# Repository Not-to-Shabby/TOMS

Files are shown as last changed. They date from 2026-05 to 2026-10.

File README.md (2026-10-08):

# Transportation Occupancy Monitoring System (TOMS)

> **TOMS v2 is in progress.** The system described below (Master/Slave terminals, Flutter app) is the first generation and now lives in [`archive/`](archive/README.md). v2 uses the conductor's phone as the card reader: see [`toms_android/`](toms_android/README.md), [`toms_backend/`](documentation/v2_progress.md) and [`toms_web/`](toms_web/), and the design notes in [`documentation/v2_decisions.md`](documentation/v2_decisions.md) and [`documentation/v2_progress.md`](documentation/v2_progress.md). The hardware drawings below are still current.

TOMS is a secure, offline-first, contactless transit ticketing and manifest system designed to modernize public utility vehicle operations (such as minibuses and modern jeepneys in Iligan City, Philippines). It replaces traditional manual ticket issuance and cash collection with a robust Master-Slave-Phone network architecture utilizing contactless NFC-DEP Peer-to-Peer communication, ESP-NOW wireless synchronization, and USB CDC-ACM mobile integration.

---

## 🚀 System Architecture (v1, archived)

TOMS is composed of three primary tiers:
1. **Slave Terminal (Tap / Interface Device)**
   * **Hardware:** Built on the ultra-compact **ESP32-S3 Super Mini** development board.
   * **Power Management:** Onboard TP4054 battery charging IC management with built-in resistor voltage divider (ratio 0.5) connected to GPIO 1 (ADC1_CH0) to monitor LiPo cell status.
   * **Peripherals:** PN532 NFC transceiver (configured in Target mode for NFC-DEP P2P at 424 kbps), ST7735S 128×160 TFT LCD (using LVGL 8.3 UI), and a tactile boarding trigger button.
   * **Functionality:** Passive interface that displays transaction UI, accepts button/tap inputs, generates QR receipts, and exchanges fast data frames with the Master.
2. **Master Handheld Terminal (Business Logic & Storage)**
   * **Hardware:** ESP32-S3 microcontroller.
   * **Functionality:** Conducts cryptographic operations, holds fare tables, acts as the transaction broker, writes records to an offline-first wear-leveled SPIFFS partition, and pipes live transactions to the operator's smartphone via USB CDC-ACM.
3. **Mobile Dashboard App (Cloud Gateway)**
   * **Framework:** Native Android App built with Flutter.
   * **Functionality:** Acts as the operator's primary screen, displays real-time boarding analytics, caches transactions in a local SQLite database, and pushes buffered records to a Supabase backend when an active internet connection is detected.

---

## 🛠️ Hardware Design Documentation

The physical prototypes were developed using Fritzing. Below are the designs (breadboard layouts, schematics, and PCB diagrams) for both the Master and Slave terminals.

### 1. Master Handheld Terminal

| View Type | Hardware Illustration |
|---|---|
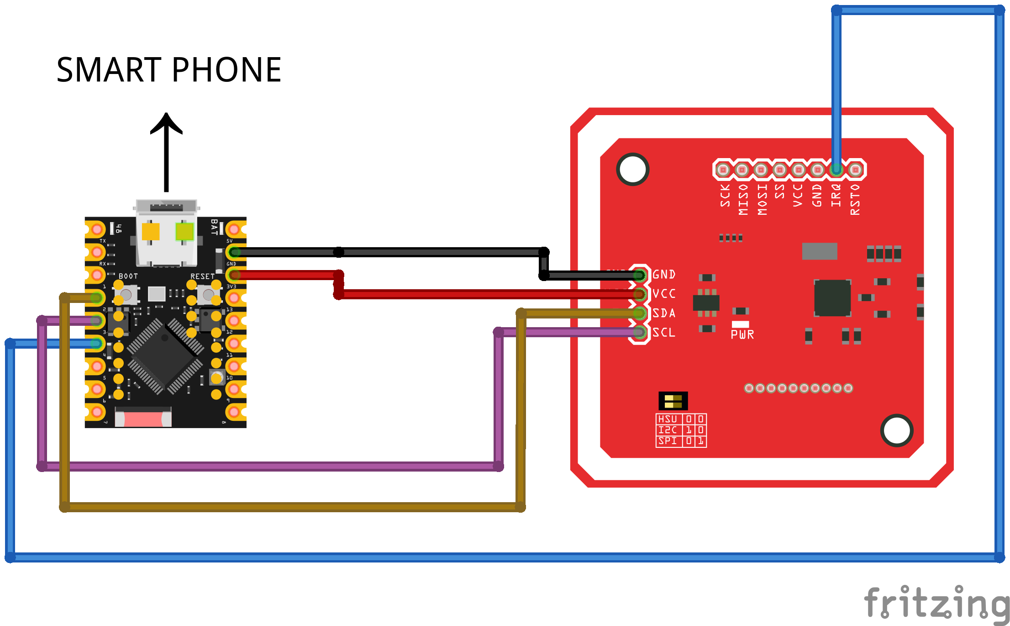
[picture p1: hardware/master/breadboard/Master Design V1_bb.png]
Master Breadboard
| **Breadboard Layout** |  |
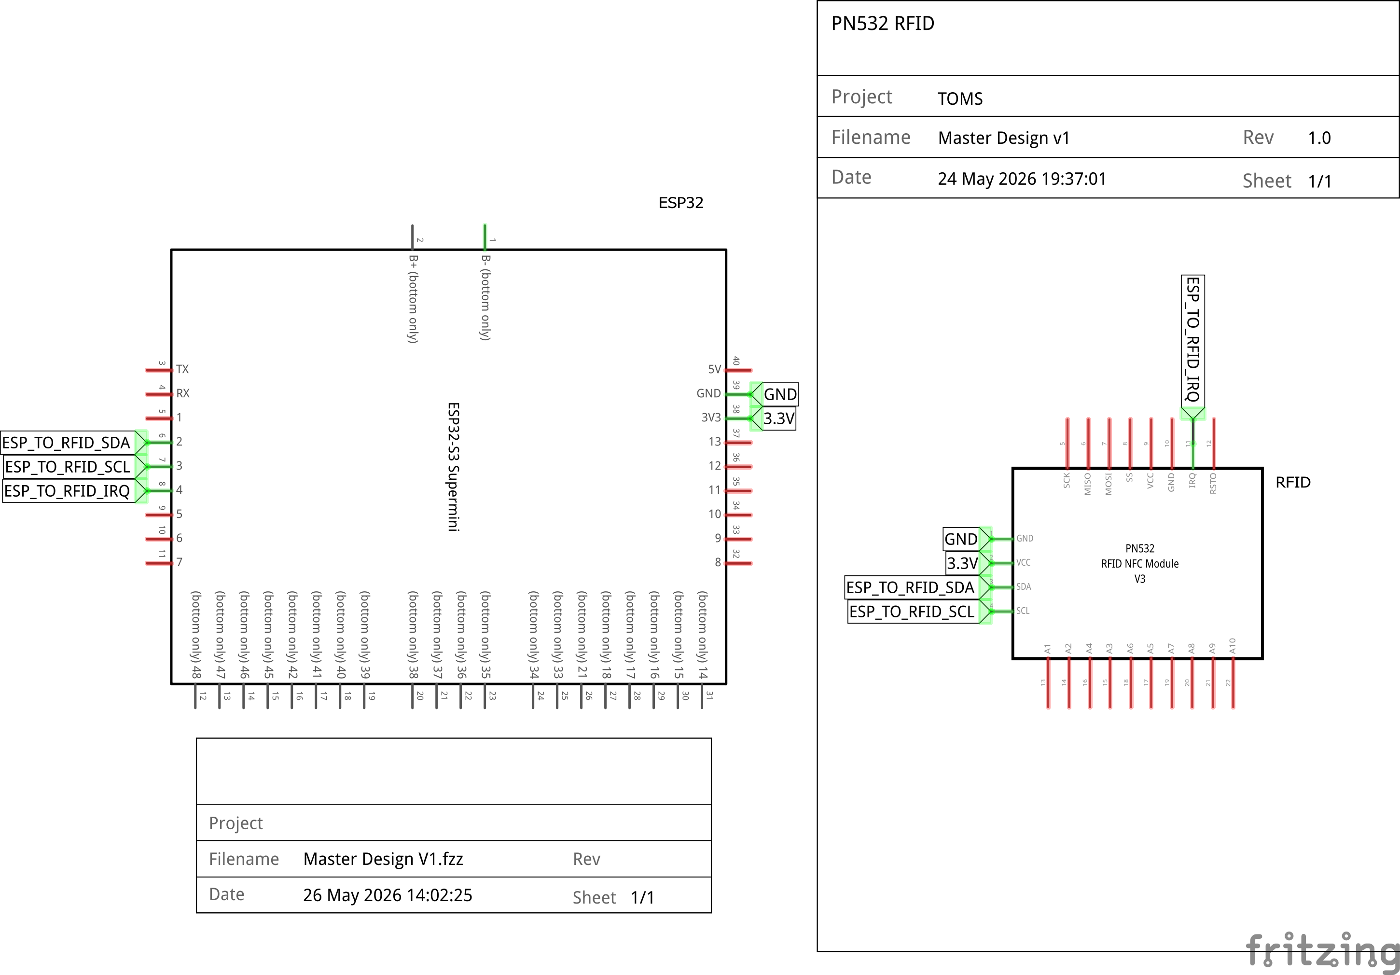
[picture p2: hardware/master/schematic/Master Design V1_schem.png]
Master Schematic
| **Schematic** |  |
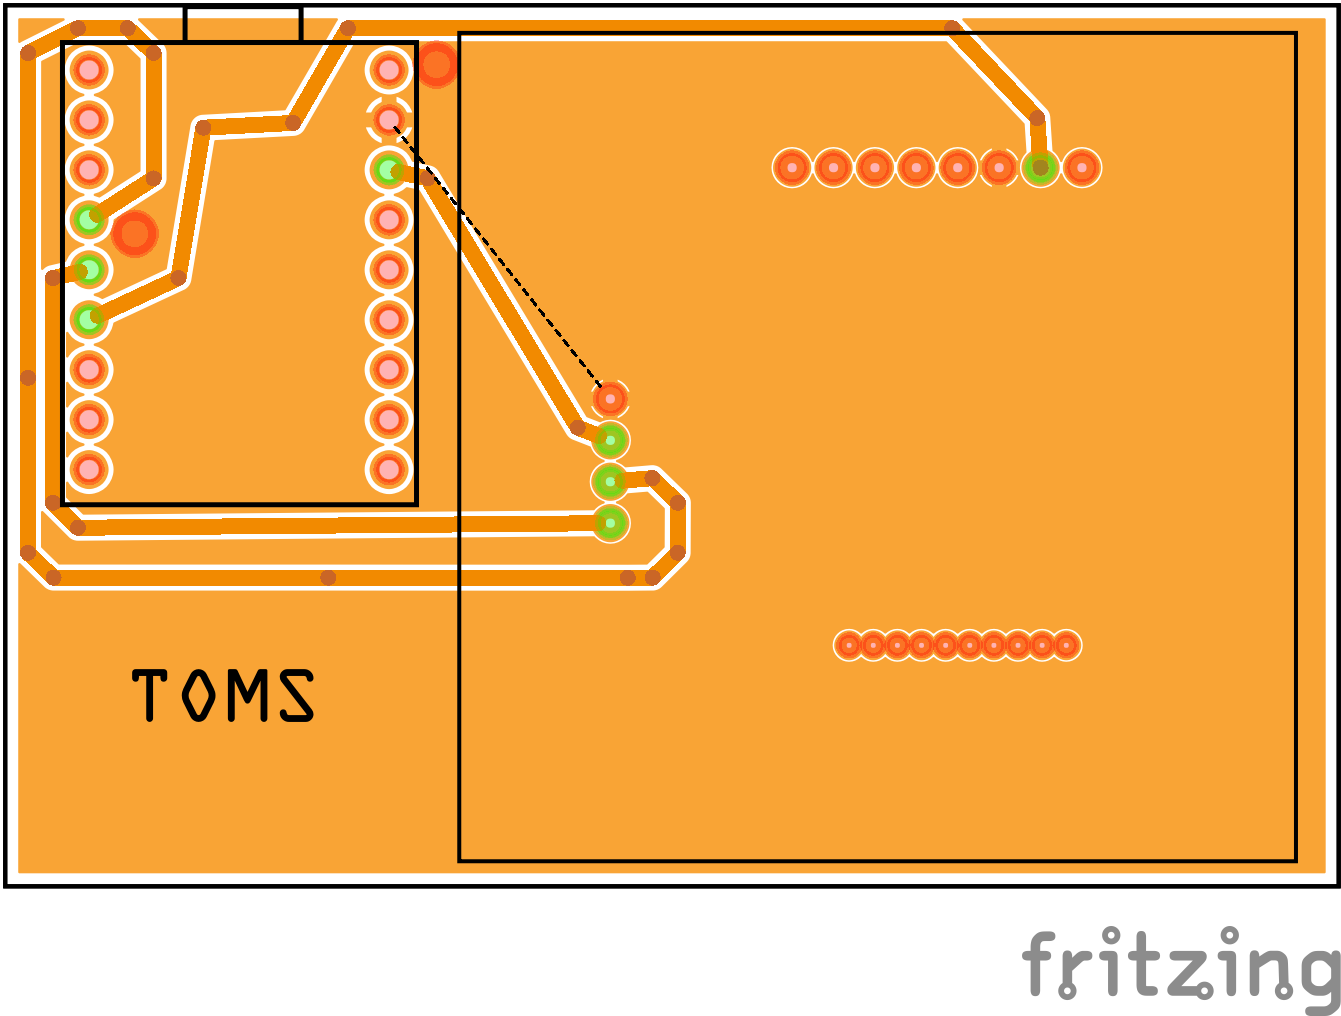
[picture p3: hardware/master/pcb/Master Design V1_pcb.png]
Master PCB
| **PCB Layout** |  |

### 2. Slave Terminal (ESP32-S3 Super Mini)

| View Type | Hardware Illustration |
|---|---|
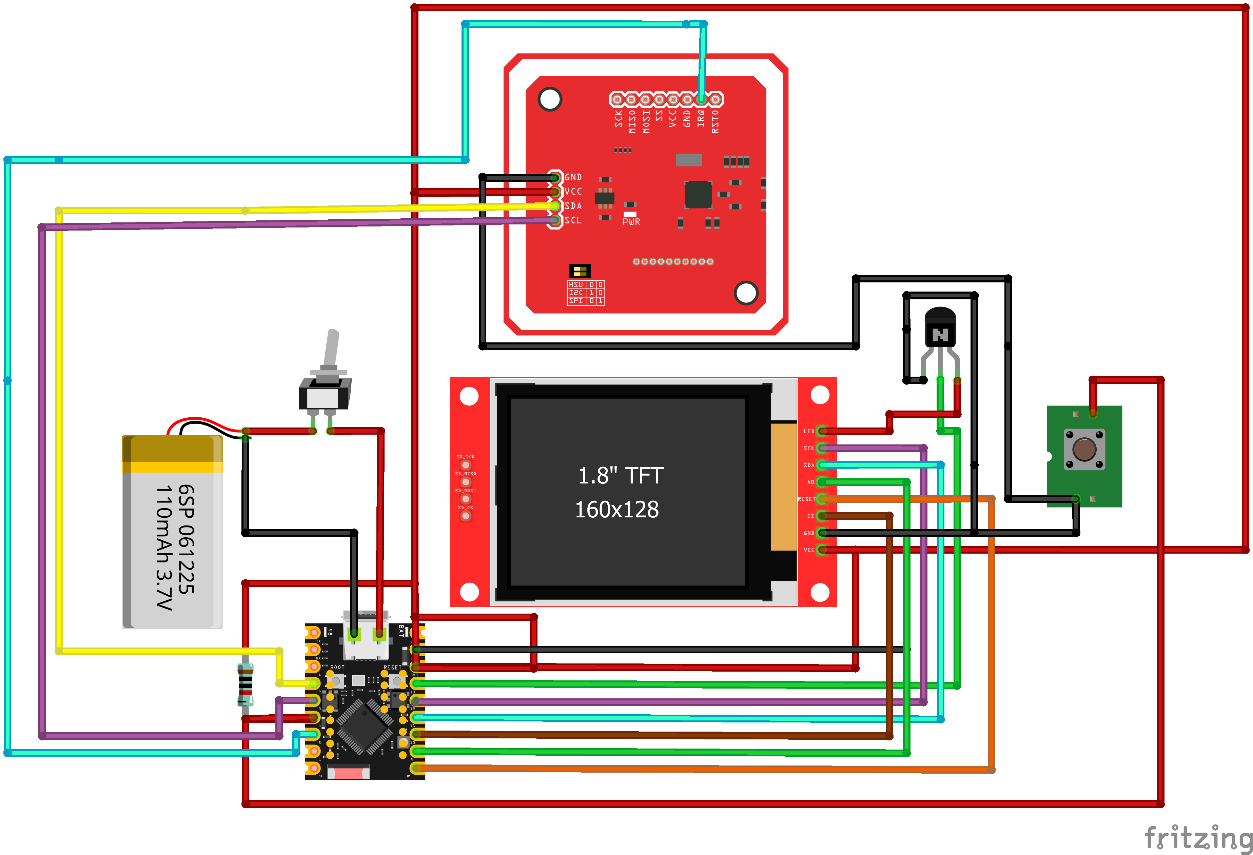
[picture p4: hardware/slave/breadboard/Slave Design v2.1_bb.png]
Slave Breadboard
| **Breadboard Layout** |  |
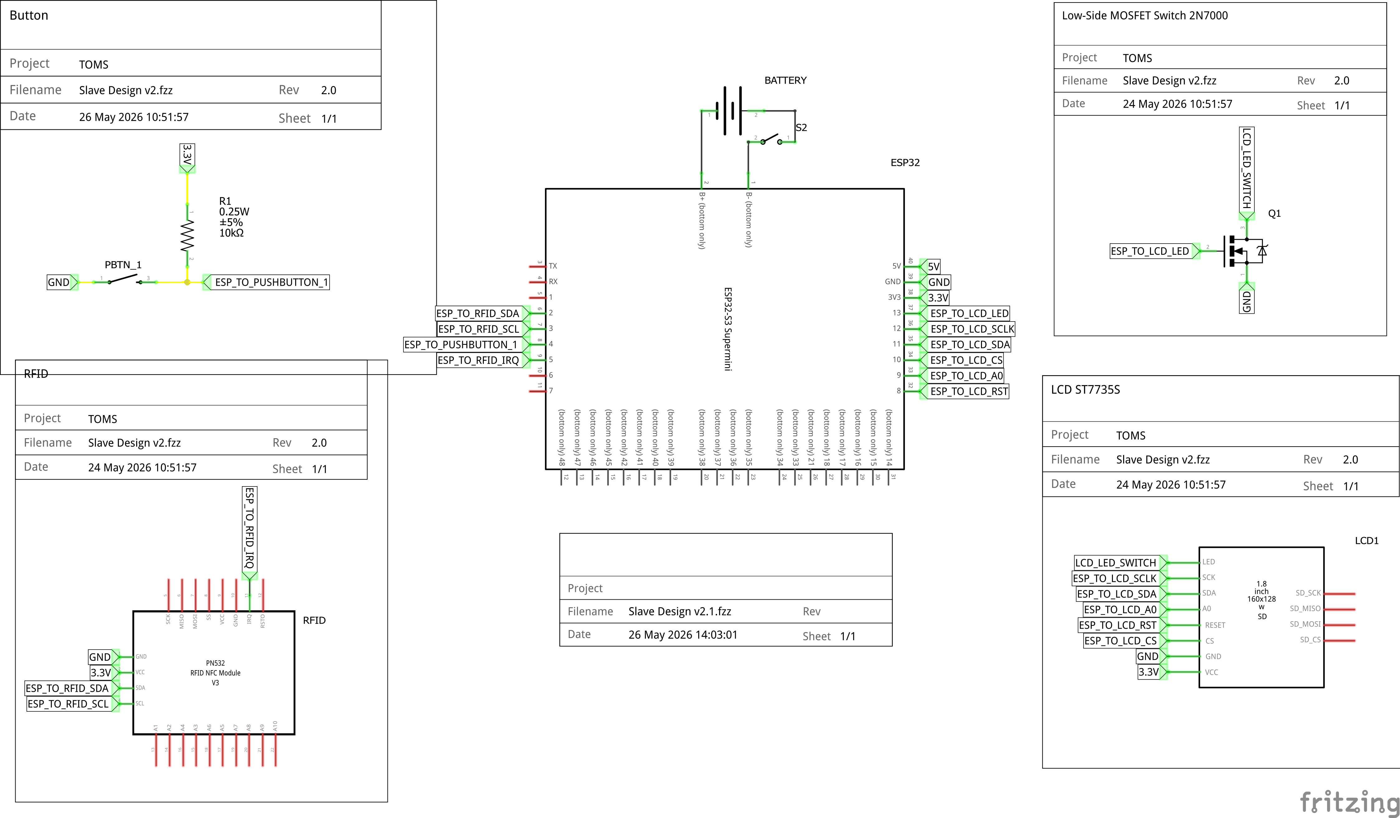
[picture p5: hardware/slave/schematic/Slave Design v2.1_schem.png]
Slave Schematic
| **Schematic** |  |
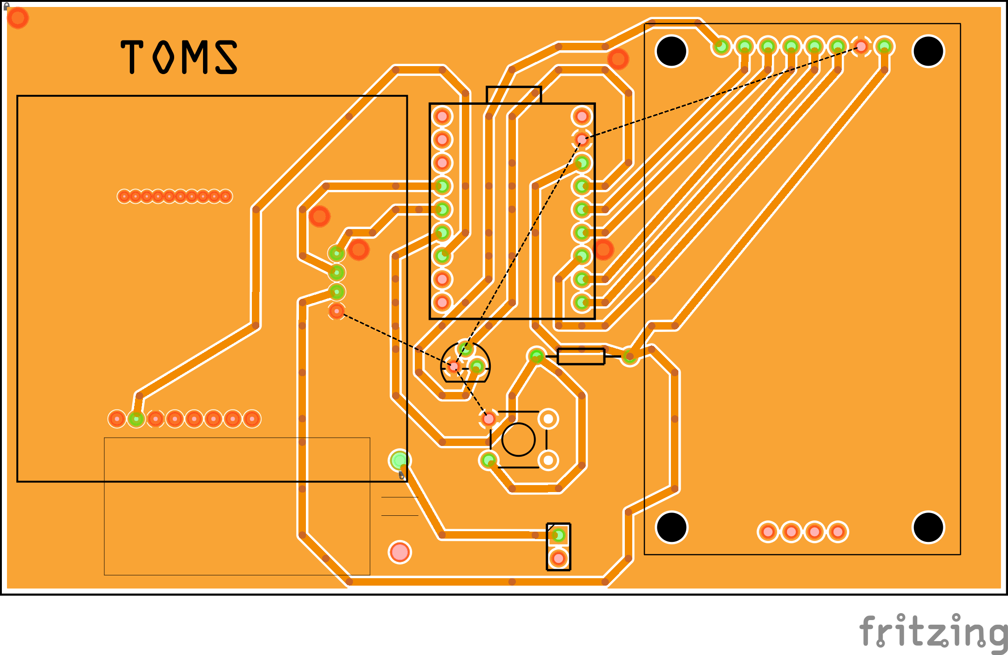
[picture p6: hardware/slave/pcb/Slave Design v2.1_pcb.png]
Slave PCB
| **PCB Layout** |  |

---

## 📡 Protocols & Security

* **Communication:** Standardized packet structure (`protocol.h`) with a 2-byte synchronization header (`0xAA55`), 1-byte length, 1-byte message type, 1-byte sequence number, variable payload, and a 2-byte CRC-16-CCITT checksum.
* **Optimistic NFC-DEP Transactions:** Master acts as the Initiator (`InJumpForDEP`) and Slave as the Target (`TgInitAsTarget`). A dictionary-based compression reduces boarding commands to 6 bytes to minimize RF communication window latency.
* **Authentication:** Device eFuse MAC validation combined with link-layer ESP-NOW CCMP (AES-128) security.

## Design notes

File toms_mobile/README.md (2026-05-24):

# toms_mobile

A new Flutter project.

## Getting Started

This project is a starting point for a Flutter application.

A few resources to get you started if this is your first Flutter project:

- [Lab: Write your first Flutter app](https://docs.flutter.dev/get-started/codelab)
- [Cookbook: Useful Flutter samples](https://docs.flutter.dev/cookbook)

For help getting started with Flutter development, view the
[online documentation](https://docs.flutter.dev/), which offers tutorials,
samples, guidance on mobile development, and a full API reference.

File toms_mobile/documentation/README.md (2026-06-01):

# TOMS Mobile Application Documentation

This document describes the application design, architecture, database configurations, APIs, user interface, program flow, and testing procedures for the TOMS (Transportation Occupancy Monitoring System) Flutter Mobile Application. It has been updated to reflect the completion of **Phase 4a**.

## System Architecture

The TOMS Mobile Application is a Flutter-based mobile app designed to run on the conductor's Android device. It acts as the orchestration bridge between the physical vehicle hardware (Master ESP32-S3), the passenger, and the cloud database:

1. Establishes a local physical link with the Master controller using an Android USB OTG connection, operating over a virtual serial CDC-ACM interface.
2. Serves as the real-time operator interface, showing vehicle occupancy, active routes, current passenger records, and GPS-aware proximity alarms.
3. Provides an offline-first transaction database, caching passenger boarding logs locally when mobile signals are unavailable.
4. Orchestrates synchronisation queues to push cached passenger records to the company REST API, using secure JWT-based authentication.

```mermaid
graph TD
    subgraph Conductor Mobile
        UI[Flutter Home Shell]
        AppState[AppState Provider]
        Sqlite[(SQLite Local Cache)]
        UsbService[UsbService CDC-ACM]
        SyncService[SyncService]
        AuthService[AuthService]
        GpsService[Gps & Proximity]
    end
    
    subgraph Vehicle Hardware
        Master[ESP32-S3 Master]
        Slave[Slave Terminals]
    end
    
    subgraph Cloud
        Backend[(Company Server / Cloud Database)]
    end
    
    UsbService -- USB OTG / JSON-Line -- Master
    Master -- ESP-NOW / P2P -- Slave
    UsbService --> AppState
    AppState --> UI
    AppState --> Sqlite
    GpsService --> AppState
    AuthService --> SyncService
    AppState --> SyncService
    SyncService -- HTTPS REST (JWT Auth) -- Backend
```

## Application Architecture

The mobile application utilizes a clean Model-View-Service architecture built around the Provider state-management framework to achieve separation of concerns:

* **View Layer (Material 3)**:
  * `HomeShell`: A Swipeable PageView bridging the primary workflows.
  * `BoardingScreen`: Full-screen UI for generating passenger tickets and managing the pending queue.
  * `DashboardScreen`: Real-time Occupancy Panel, active passenger slots, and diagnostic console.
  * `ShiftHistoryScreen`: Grouped daily transaction logs with JSON export capabilities.
* **Service Layer**: Decoupled singletons managing background hardware and data tasks:
  * `UsbService`: Manages USB serial lifecycles, parses incoming JSON frames.
  * `AuthService`: Manages JWT tokens in secure storage and vehicle assignment states.
  * `DatabaseService`: Manages SQLite operations, schema upgrades, and local query execution.
  * `SessionService`: Manages boarding queues, active passenger sessions, base fare calculations, and discount models.
  * `OccupancyService`: Computes dynamic slot allocations and publishes real-time occupancy rates based on vehicle capacity.
  * `GpsService & ProximityService`: Tracks the bus's physical location against mapped `TransitStops` and triggers local alarms when nearing a passenger's destination.
  * `ConnectivityService`: Monitors network status changes using the connectivity plugin.
  * `SyncService`: Stores events locally and flushes the synchronization queue automatically upon reconnection, providing progress callbacks to the UI.
* **State Orchestrator (`AppState`)**: Directs the flow between hardware events, UI state, and database transactions.

## Offline-First & Shift Lifecycles

The app implements a strict offline-first design:
* **Auth & Assignment**: The app is gated behind `LoginScreen` and `VehicleAssignmentScreen`. A shift does not begin until the conductor selects a vehicle, locking in the `maxCapacity`.
* **Local Caching**: Incoming USB passenger events (NFC taps, button presses) are evaluated against the pending queue, serialised into local SQLite tables, and immediately confirmed locally.
* **Store-and-Forward Sync**: The `SyncService` operates asynchronously. It batches unsynced records from the SQLite database. If the device is offline, it waits. Upon reconnection, it flushes the queue to the backend. A `_SyncStatusBar` provides UI feedback.
* **End of Shift**: Conductors invoke `AppState.endShift()` to clear active sessions and log out of the vehicle. If the backend is unavailable, the conductor can manually extract their shift logs as a JSON file via Bluetooth or Email using `share_plus`.

## Hardware Pin Assignment & Connectivity

Because the mobile application is a software layer running on commercial Android hardware, it does not directly manage low-level GPIO pin configurations. Instead, it accesses hardware interfaces through:
* **Interface**: USB Controller on the Android SoC.
* **Protocol Mode**: Configured in USB Host Mode via the Android SDK (`android.hardware.usb.host` feature).
* **Physical Connection**: Android USB Type-C interface connected to the Master ESP32-S3 via a USB OTG cable.

## Required Libraries

The following dependencies are declared inside `pubspec.yaml`:

1. `usb_serial`: Wraps Android USB host APIs to discover, open, and communicate with USB-to-serial chips without device root.
2. `provider`: State-management container used to inject services.
3. `sqflite`: SQLite database plugin for local caching.
4. `flutter_secure_storage`: Encrypts the company JWT token and securely stores the conductor's credentials.
5. `geolocator`: Accesses phone GPS for coordinate tracking.
6. `vibration` & `flutter_local_notifications`: Sounds haptic and visual alarms for unpaid passengers approaching their stops.
7. `share_plus`: Exports shift JSON summaries for offline terminal reconciliation.
8. `connectivity_plus`: Listens to network connectivity events to trigger automatic API syncing.
9. `lucide_icons` & `google_fonts`: Tailwind UI / modern typography.

## Protocol Used in Hardware Abstraction Layer

The application-level HAL protocol uses newline-delimited JSON objects transmitted over the USB virtual serial port at 115200 baud:

* **Conductor Phone to Master Commands**:
  * Handshake: `{"cmd":"handshake"}`
  * Get Status: `{"cmd":"get_status"}`
  * Board Passenger: `{"cmd":"board", "uid":"...", "fare":1300, "seat":1, "route":1, "vehicle_id":"..."}`
* **Master to Conductor Phone Events**:
  * Acknowledgment: `{"evt":"ack", ...}`
  * Status Diagnostics: `{"evt":"status", ...}`
  * NFC Card Tap: `{"evt":"nfc_tap", "uid":"A1B2C3D4E5F6", "seat":0}`
  * Button Boarding Request: `{"evt":"button_press", "mac":"A1:B2:C3:D4:E5:F6"}`
  * Passenger Alighted: `{"evt":"release", "mac":"A1:B2:C3:D4:E5:F6"}`
  * Error Warning: `{"evt":"error", "msg":...}`

## Program Flow Table

| Step | State/Action | Condition / Input | Output / State Transition |
|---|---|---|---|
| 1 | Boot Initialization | App launch | Instantiates SQLite services, registers providers, validates JWT token. Routes to `LoginScreen` or `VehicleAssignmentScreen`. |
| 2 | Shift Start | Vehicle Selected | Sets `maxCapacity`, routes to `HomeShell`, triggers automatic USB scanning loop. |
| 3 | Boarding Prep | Conductor interacts | Conductor selects destination/type. GPS auto-suggests nearest boarding stop. Passenger added to `SessionService.pendingQueue`. |
| 4 | USB Device Connected | Master USB plugged in | Opens serial port, 115200 baud, transmits `handshake`. Updates Dashboard status. |
| 5 | Passenger Boarding Request | NFC Tap OR Button Press | Fires `nfc_tap` / `button_press` over USB. App checks if a queued ticket exists, assigns the ticket, sends `board` command, and pushes a `board` event to `SyncService`. |
| 6 | Payment Trigger | Conductor collects fare | Conductor collects cash. Marks slot as PAID. Clears proximity alarms. Pushes a `payment` event to sync queue. |
| 7 | Proximity Alarm | GPS approaches destination | `ProximityService` calculates distance < 200m. If unpaid, triggers `Vibration` and `ProximityAlarmBanner`. |
| 8 | Passenger Alighting | Slave Long Press (3s) | Slave sends release notification. Phone receives `release` event, frees the slot, and syncs release. |
| 9 | Cloud Sync Queue | Event added to sync queue | If connectivity is detected, POSTs to backend using JWT Auth. Updates UI sync badge on success. |

## Security Architecture

1. **Network Security**: Connects to cloud endpoints over HTTPS (TLS encryption) to prevent MITM attacks.
2. **API Authentication**: The `SyncService` dynamically requests a bearer token from `AuthService` (`Authorization: Bearer <token>`). Tokens are securely encrypted on disk.
3. **Data Protection**: Local transactions are segregated by shift. Debug logs are routed through Flutter's `debugPrint`, preventing leakage to Android logcat in release builds.

## Planned Features (Upcoming Phases)

1. **Route Builder Syncing**: Dynamic injection of `TransitStop` coordinates from the backend API replacing the static `stops.json`.
2. **Master USB Configuration Push**: Pushing updated fare dictionaries and vehicle capacities dynamically to the Master's NVS memory upon shift start.

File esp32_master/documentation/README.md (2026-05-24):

# TOMS Master Firmware Documentation

This document describes the firmware design, system architecture, pin assignments, software framework, APIs, program flow, and testing procedures for the TOMS (Transit Monitoring System) Master device.

## System Architecture

The Transit Monitoring System (TOMS) is designed to coordinate vehicle passenger check-ins, manage fare calculations, and store transactional records for public transit operations. The Master device is the central controller inside the vehicle:

1. Connects to the conductor's Android mobile device (running the Flutter app) via a USB CDC-ACM virtual serial interface (USB OTG).
2. Manages synchronization with Slave devices via two interfaces: **NFC-DEP peer-to-peer** (PN532 module, physical tap) or wirelessly (ESP-NOW).
3. Buffers and logs all check-in events in a local SPIFFS flash partition to prevent data loss in signal dead zones (offline-first architecture).
4. Monitors battery voltage using an integrated ADC channel to report power status.
5. Uses a **dictionary-based compact NFC exchange** — both Master and Slave share a pre-synced fare dictionary. NFC payloads carry only indices (6 bytes), not raw data (40 bytes).

```mermaid
graph TD
    subgraph Vehicle Cabin
        Master[ESP32-S3 Master Controller]
        Slave[ESP32-S3 Slave Unit]
    end
    
    subgraph Conductor UI
        Mobile[Android Flutter App]
    end
    
    subgraph Cloud Backend
        Supabase[(Supabase Database)]
    end
    
    Master -- USB OTG / CDC-ACM JSON-Line -- Mobile
    Master -- ESP-NOW 2.4 GHz AES-256 -- Slave
    Master -- PN532 NFC-DEP P2P I2C -- Slave
    Mobile -- HTTPS / Offline Sync -- Supabase
```

## Firmware Architecture

The Master firmware is built on top of the ESP-IDF RTOS environment, distributing tasks across the dual cores of the ESP32-S3 microcontroller to ensure real-time responsiveness.

* Core 0: Manages the USB CDC serial communication thread, the NFC P2P sync task (PN532 Initiator), SPIFFS storage operations, and battery monitoring.
* Core 1: Dedicated to the latency-critical ESP-NOW wireless network stack, processing wireless packets and driving immediate acknowledgments.

```mermaid
graph TD
    subgraph Core 0
        usb_cdc_task[USB CDC Task]
        nfc_sync_task[NFC Sync Task - PN532 Initiator]
        storage_flush_task[Storage Flush Task]
        power_adc[Battery Monitoring]
    end
    subgraph Core 1
        espnow_handler_task[ESP-NOW Handler Task]
    end
    
    app_main[app_main Entry] --> usb_cdc_task
    app_main --> nfc_sync_task
    app_main --> espnow_handler_task
    app_main --> storage_flush_task
```

## Firmware Design

The firmware relies on an event-driven design pattern utilizing FreeRTOS queues and callbacks. Each peripheral driver (USB, NFC, ESP-NOW) is decoupled from the main coordination logic:
* Incoming USB packets from the conductor's phone trigger a receive callback which executes parsing routines.
* The NFC PN532 Initiator task polls for NFC-DEP targets every 250ms. On tap, the Slave's NFCID3 (containing its eFuse MAC) identifies it without a separate handshake.
* A **two-phase optimistic transaction** model is used: Phase 1 (NFC tap) increments the passenger counter immediately, Phase 2 (ESP-NOW PASSENGER_BOARD) confirms the transaction asynchronously.
* Wireless ESP-NOW messages are loaded into a thread-safe FreeRTOS queue and processed sequentially by a dedicated high-priority task.
* Transactions are cached in binary format inside SPIFFS files and written in blocks to extend flash endurance.
* A **fare dictionary** stored in NVS enables compact NFC payloads — only a fare_id index (1 byte) is transmitted instead of full fare/route data.

## Hardware Pin Assignment

The Master device is built on the ESP32-S3 Super Mini platform. The hardware pins are configured as follows:

| Interface | Pin Name | GPIO Pin | Pin Type | Description |
|---|---|---|---|---|
| NFC I2C | TOMS_NFC_I2C_SDA | GPIO 2 | Bidirectional | I2C data line to PN532 module |
| NFC I2C | TOMS_NFC_I2C_SCL | GPIO 3 | Output | I2C clock line to PN532 module |
| NFC IRQ | TOMS_NFC_IRQ_PIN | GPIO 4 | Input | PN532 interrupt (active LOW, tag ready) |
| Power | TOMS_BATTERY_ADC_CHANNEL | GPIO 1 (ADC1_CH0) | Analog Input | Measures battery voltage via a 0.5 voltage divider |
| USB OTG | Native USB D- | GPIO 19 | Bidirectional | Native USB signal for CDC-ACM virtual serial port |
| USB OTG | Native USB D+ | GPIO 20 | Bidirectional | Native USB signal for CDC-ACM virtual serial port |

## Software Framework Used

The firmware is developed using PlatformIO with the Espressif ESP-IDF software development framework (v5.0.0 or higher). This framework provides the underlying FreeRTOS kernel, virtual file system (VFS) interface, hardware abstraction drivers, and wireless protocol stacks.

## Required Libraries

The following dependencies are declared and loaded via the IDF Component Manager:

1. espressif/esp_tinyusb (version ^1): Configures the ESP32-S3's internal USB OTG controller into CDC-ACM device class mode.
2. mbedtls: Part of the ESP-IDF core library, providing hardware-accelerated cryptographic operations.
3. esp_wifi and esp_now: Core ESP-IDF libraries managing the RF driver, Wi-Fi Station layer, and raw connectionless frame transfers.
4. esp_spiffs and nvs_flash: Core ESP-IDF subsystems for file storage and key-value storage.
5. PN532 I2C driver: Custom shared library (`shared_lib/pn532/`) implementing the NXP PN532 NFC controller protocol over I2C.

## Protocol Used in Hardware Abstraction Layer

The system uses a custom application-level framing protocol (defined in `protocol.h`) to encapsulate messages sent over both NFC-DEP and wireless ESP-NOW:

* framing: `[Sync Word (0xAA55)][Length (1 byte)][Type (1 byte)][Sequence (1 byte)][Payload (0-240 bytes)][CRC-16-CCITT (2 bytes)]`
* NFC compact format: `[MSG_TYPE (1 byte)][fare_id (1 byte)][seat (1 byte)][timestamp (4 bytes)]` — 7 bytes total for boarding commands
* encryption: Wireless payloads (ESP-NOW) are encrypted with application-level AES-256-CBC using a key loaded from NVS, running on top of ESP-NOW's native AES-128 CCMP link encryption.
* fare dictionary: Both devices share a pre-synced lookup table in NVS indexed by `fare_id`. Only the index is transmitted over NFC.

## Program Flow Table

| Step | State/Action | Condition / Input | Output / State Transition |
|---|---|---|---|
| 1 | Boot Initialization | Power on / Reset | Initializes NVS, mounts SPIFFS, loads AES key, initializes Wi-Fi/ESP-NOW, configures USB CDC, initializes PN532 NFC, loads fare dictionary, reads ADC, launches FreeRTOS tasks. Transition to Idle Listening. |
| 2 | Idle Listening | Waiting for interrupts / messages | NFC task polls InJumpForDEP every 250ms, USB CDC stream is monitored, ESP-NOW event queue is processed. |
| 3 | USB Message Received | JSON command over USB CDC | Decodes JSON command. If `handshake`, replies with device info (MAC, battery, pending logs). If `get_status`, returns full diagnostics. If `sync_fare_table`, processes config. |
| 4 | NFC Tap Detection | PN532 InJumpForDEP succeeds | DEP link established. Slave NFCID3 = eFuse MAC extracted. Phase 1: Optimistic count — passenger counter incremented, phone notified with `nfc_tap` event. |
| 5 | NFC Board Command | DEP link active | Sends compact NFC_BOARD_CMD (fare_id + seat + timestamp, 6 bytes) via InDataExchange. Slave responds with NFC_ACK. Link released. Cooldown (1.5s anti-double-tap). |
| 6 | ESP-NOW Confirmation | Receives TOMS_MSG_PASSENGER_BOARD wirelessly | Phase 2: Transaction confirmed. Logs passenger event to SPIFFS. Forwards confirmed transaction to phone via USB. |
| 7 | ESP-NOW Button Event | Receives TOMS_MSG_BUTTON_PRESS wirelessly | Transmits `button_press` event to Mobile via USB. Sends wireless ACK. Dispatches TOMS_MSG_BOARD_COMMAND back to the sender Slave MAC. |
| 8 | Periodic Storage Flush | 60 seconds timer elapsed | Storage task runs, clears old synced transaction files (`.done`), and logs active memory usage stats. |

## Program Flowchart

```mermaid
flowchart TD
    Init[Boot & Subsystem Init] --> Idle[Idle Listening Loop]
    
    Idle -->|USB JSON Rx| USB_Cmd{Decode Command}
    USB_Cmd -->|handshake| USB_Handshake[Send device status JSON] --> Idle
    USB_Cmd -->|get_status| USB_Status[Send diagnostic status JSON] --> Idle
    USB_Cmd -->|sync_fare_table| USB_Fare[Process/Sync Fare Configuration] --> Idle
    
    Idle -->|PN532 InJumpForDEP| NFC_Detect{NFC Target Found?}
    NFC_Detect -->|No| Idle
    NFC_Detect -->|Yes| NFC_Tap[Phase 1: Optimistic Count - Notify Phone]
    NFC_Tap --> NFC_Send[Send NFC_BOARD_CMD 6 bytes]
    NFC_Send --> NFC_ACK{Slave ACK?}
    NFC_ACK -->|Yes| NFC_Cooldown[1.5s Anti-Double-Tap Cooldown] --> Idle
    NFC_ACK -->|No/Error| NFC_Reset[Reset PN532] --> Idle
    
    Idle -->|ESP-NOW Rx| EN_Msg{Decode Msg Type}
    EN_Msg -->|PASSENGER_BOARD| EN_Confirm[Phase 2: Confirm Transaction - Log & Forward] --> Idle
    EN_Msg -->|BUTTON_PRESS| EN_Button[Forward to Phone & Send BOARD_COMMAND via ESP-NOW] --> Idle
    EN_Msg -->|HEARTBEAT| EN_Hb[Log Slave presence] --> Idle
    
    Idle -->|60s Timer| Storage_Task[Erase synced .done files & log stats] --> Idle
```

## APIs in the Codebase

### Implemented APIs

* `int toms_storage_init(void)`: Mounts VFS SPIFFS and initializes the NVS flash interface.
* `bool toms_storage_log_event(const toms_passenger_event_t *event)`: Appends a transaction binary packet to the active SPIFFS file.
* `int toms_storage_get_pending_count(void)`: Returns the number of unsynced transaction files currently cached.
* `bool toms_storage_read_pending(uint8_t *buf, size_t buf_size, size_t *out_len, char *fname)`: Reads an unsynced transaction file.
* `bool toms_storage_mark_synced(const char *fname)`: Renames a file by changing its extension to `.done`.
* `void toms_storage_cleanup(void)`: Iterates over the storage partition and deletes all files marked `.done`.
* `int toms_crypto_init(void)`: Loads the AES-256 key from NVS.
* `bool toms_crypto_encrypt(...)`: Encrypts a payload buffer with AES-256-CBC.
* `bool toms_crypto_decrypt(...)`: Decrypts an IV-prefixed AES-256-CBC ciphertext buffer.
* `int toms_espnow_init(const uint8_t *pmk)`: Initializes Wi-Fi in Station mode and sets up ESP-NOW.
* `bool toms_espnow_send(const uint8_t *dst_mac, const toms_packet_t *pkt)`: Encrypts, serializes, and transmits a wireless packet.
* `int toms_usb_cdc_init(void)`: Configures the USB controller and CDC descriptors.
* `int toms_usb_cdc_send(const char *json)`: Pushes a JSON string to the mobile app.
* `int toms_nfc_sync_init(void)`: Initializes PN532 over I2C as NFC-DEP Initiator.
* `void toms_nfc_sync_set_tap_cb(toms_nfc_tap_cb_t cb)`: Registers callback for NFC tap detection.
* `void toms_nfc_sync_set_fare(uint8_t fare_id, uint8_t seat)`: Sets active fare for next NFC tap.
* `void toms_nfc_sync_task(void *arg)`: NFC Initiator polling task (FreeRTOS).
* `toms_nfc_state_t toms_nfc_sync_get_state(void)`: Returns current NFC state.
* `esp_err_t toms_fare_dict_load(toms_fare_dict_t *dict)`: Loads fare dictionary from NVS.
* `const toms_fare_entry_t *toms_fare_dict_lookup(const toms_fare_dict_t *dict, uint8_t fare_id)`: Looks up a fare entry by ID.
* `int toms_power_init(void)`: Configures the ADC1 peripheral for battery readings.
* `uint32_t toms_power_get_battery_mv(void)`: Returns raw battery voltage in millivolts.
* `uint8_t toms_power_get_battery_pct(void)`: Returns battery state of charge percentage.

### Planned to be Implemented

* `bool toms_storage_set_fare_table(const uint8_t *data, size_t len)`: Planned API to persist updated route pricing tables received from the mobile app to NVS.
* `bool toms_storage_get_fare_table(uint8_t *buf, size_t max_len, size_t *out_len)`: Planned API to read pricing tables from NVS for syncing to Slaves.
* `void toms_power_enter_light_sleep(void)`: Planned power-saving API.

## Planned / Implemented User Acceptance Testing (UAT)

1. USB OTG Communication: Conductor connects their Android phone running the Flutter app. The Master must establish a virtual serial link, complete the handshake within 1.5 seconds, and report its battery percentage and file counters.
2. NFC Tap Boarding: Conductor taps a Slave device against the Master's PN532 antenna. The Master must detect the NFC-DEP link, read the Slave's UID from NFCID3, send a compact BOARD_CMD (6 bytes), receive ACK, and notify the phone with an optimistic `nfc_tap` event — all within 300ms.
3. ESP-NOW Confirmation: After the Slave processes the boarding (shows fare, renders QR), it sends PASSENGER_BOARD via ESP-NOW. The Master must confirm the transaction and forward it to the phone.
4. Offline Logging Validation: Disconnect the mobile device. Trigger 10 boarding events. The Master must successfully write all 10 records to SPIFFS. Reconnect the mobile device; the Master must sync the 10 stored records.
5. AES-256 Payload Security: Capture ESP-NOW traffic using an external sniffer. Payload content must be fully encrypted.

## Testing and Validation (Hardware Focus: Module & Power Testing)

### Power Measurement and Calibrations
* Battery Monitor Voltage Divider: The hardware employs a 100k ohm / 100k ohm (0.5 ratio) resistor divider to bring battery voltage (3.0V - 4.2V) within the ESP32-S3's ADC input range.
* ADC Calibration: The codebase utilizes `esp_adc_cal_characterize` to configure raw ADC counts against factory-fused eFuse calibration values.
* Threshold Validation: The firmware implements a low battery warn threshold at 3300mV (~20% capacity) and a critical shutdown threshold at 3100mV.

### Module Interface Verification
* PN532 I2C Communication: The I2C bus operates at 400 kHz. IRQ pin (GPIO 4) is used for zero-latency response detection. The PN532 firmware version is verified on every boot.
* NFC-DEP Link Timing: At 424 kbps, the NFC data exchange (6-byte command + 1-byte ACK) takes under 1ms on the RF layer. Total tap time is ~100-150ms, dominated by DEP link setup.
* RF Verification: Wi-Fi output power is adjusted to ensure reliable ESP-NOW operation within a 15-meter vehicle cabin radius.

## Potential TODOs in the Codebase

1. Parsing of JSON Fare Tables: Integrate `cjson` parser inside `usb_cdc.c` / `app_main.c` to parse fare arrays received over USB and update the fare dictionary.
2. NVS Storage for Fare Tables: Implement `toms_fare_dict_save()` to persist fare dictionaries received from the phone and sync to Slaves.
3. Secure Key Provisioning: Establish a protocol command to provision the AES-256 key via USB CDC on assembly.

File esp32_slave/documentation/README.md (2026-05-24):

# TOMS Slave Firmware Documentation

This document describes the firmware design, system architecture, pin assignments, software framework, APIs, program flow, and testing procedures for the TOMS (Transit Monitoring System) Passenger Slave device.

## System Architecture

The Passenger Slave device acts as the interface for passengers in the vehicle cabin. Its main responsibilities are:

1. Displaying welcoming prompts, fare details, seat numbers, and transaction status screens.
2. Generating and rendering high-contrast QR codes on the screen that act as passenger check-in receipts.
3. Receiving manual check-in requests via a physical wake-up button.
4. Communicating with the Master device via **NFC-DEP peer-to-peer** (PN532 module, physical tap) or wirelessly (ESP-NOW).
5. Minimizing battery power consumption using aggressive deep sleep modes, waking up only upon button presses or timer-based heartbeats.
6. Using a **fare dictionary** to expand compact NFC commands into full boarding data locally.

```mermaid
graph TD
    subgraph Vehicle Cabin
        Master[ESP32-S3 Master Controller]
        Slave[ESP32-S3 Slave Unit]
    end
    
    subgraph Slave Subsystems
        Button[Wake Button / Interrupt]
        TFT[ST7735S TFT Screen]
        LVGL[LVGL UI Engine]
        PN532_S[PN532 NFC Module - Target]
    end
    
    Master -- ESP-NOW Wireless / NFC-DEP P2P -- Slave
    Slave --> Button
    Slave --> TFT
    Slave --> LVGL
    Slave --> PN532_S
```

## Firmware Architecture

The Slave firmware is structured around a passive, master-driven architecture designed to minimize active runtime and maximize battery life. It divides operations into dedicated FreeRTOS tasks pinned to the ESP32-S3's dual cores:

* Core 0: Executes low-priority and user-interface tasks: LVGL timer ticks, physical button debouncing, NFC Target listener, and the main coordination state machine.
* Core 1: Runs the latency-sensitive wireless ESP-NOW handler task to process incoming commands and send ACKs.

```mermaid
graph TD
    subgraph Core 0
        lvgl_timer_task[LVGL UI Task]
        button_task[Button Interrupt/Debounce Task]
        nfc_sync_task[NFC Target Listener Task]
        main_logic_task[Main Orchestrator Task]
    end
    subgraph Core 1
        espnow_handler_task[ESP-NOW Task]
    end
    
    app_main[app_main Entry] --> lvgl_timer_task
    app_main --> button_task
    app_main --> nfc_sync_task
    app_main --> main_logic_task
    app_main --> espnow_handler_task
```

## Firmware Design

The firmware is designed around a passive state-machine:
* Sleep Mode: Microcontroller sits in deep sleep (current consumption under 15 microamps). It wakes via an ext0 RTC interrupt on the button or a timer.
* Timer Wake: Wakes every 5 minutes, transmits an ESP-NOW heartbeat containing its battery/status, and immediately sleeps.
* Active Mode: Wakes on button press. Initializes peripherals (including PN532 NFC as Target), starts a 30-second idle timer, and shows the Welcome screen.
* NFC Tap Handling: The PN532 waits in Target mode (TgInitAsTarget, DEP-only, IRQ-driven). When the Master taps, it receives a compact NFC_BOARD_CMD (fare_id + seat + timestamp), looks up the fare_id in its local dictionary, and triggers the boarding flow.
* Transaction Handling: Displays processing screen, fare details, and renders the QR receipt. Sends a `PASSENGER_BOARD` confirmation via ESP-NOW, and returns to Welcome.

## Hardware Pin Assignment

The Slave is implemented on the ESP32-S3 Super Mini platform. The hardware pins are configured as follows:

| Interface | Pin Name | GPIO Pin | Pin Type | Description |
|---|---|---|---|---|
| NFC I2C | TOMS_NFC_I2C_SDA | GPIO 2 | Bidirectional | I2C data line to PN532 module |
| NFC I2C | TOMS_NFC_I2C_SCL | GPIO 3 | Output | I2C clock line to PN532 module |
| NFC IRQ | TOMS_NFC_IRQ_PIN | GPIO 5 | Input | PN532 interrupt (active LOW) |
| SPI Display | TOMS_LCD_PIN_SDA | GPIO 11 | Output | SPI Master Out Slave In (MOSI) |
| SPI Display | TOMS_LCD_PIN_SCK | GPIO 12 | Output | SPI Clock (SCK) |
| SPI Display | TOMS_LCD_PIN_CS | GPIO 10 | Output | Chip Select (Active LOW) |
| SPI Display | TOMS_LCD_PIN_A0 | GPIO 9 | Output | Data / Command Selection (A0) |
| SPI Display | TOMS_LCD_PIN_RESET | GPIO 8 | Output | LCD Hardware Reset |
| SPI Display | TOMS_LCD_PIN_LED | GPIO 13 | Output | Backlight Control |
| Push Button | TOMS_BUTTON_PIN | GPIO 4 | Input (RTC) | Hardware push button with pull-up. Active LOW (ext0 wake) |

## Software Framework Used

The firmware is developed using PlatformIO with the Espressif ESP-IDF software development framework (v5.0.0 or higher).

## Required Libraries

The following dependencies are loaded via the IDF Component Manager:

1. teriyakigod/esp_lcd_st7735 (version *): Sub-driver for the ST7735 SPI LCD panel interface.
2. espressif/qrcode (version *): Lightweight QR code encoding engine.
3. lvgl/lvgl (version ~8.3.0): Light and Versatile Graphics Library for rendering layouts and animations.
4. ESP-IDF Core: Includes FreeRTOS, ESP-NOW, Wi-Fi driver, NVS flash interface, and mbedtls for AES-256-CBC decryption.
5. PN532 I2C driver: Custom shared library (`shared_lib/pn532/`) for NFC-DEP Target mode communication.

## Protocol Used in Hardware Abstraction Layer

The communications HAL layer uses two protocol formats:
* ESP-NOW framing: `[Sync Word (0xAA55)][Length (1 byte)][Type (1 byte)][Sequence (1 byte)][Payload (0-240 bytes)][CRC-16-CCITT (2 bytes)]`
* NFC compact format: `[MSG_TYPE (1 byte)][fare_id (1 byte)][seat (1 byte)][timestamp (4 bytes)]` — 7 bytes total
* fare dictionary: Both devices share a pre-synced lookup table in NVS. The Slave expands `fare_id` into full `toms_board_command_t` locally.
* encryption: ESP-NOW payloads are encrypted via AES-256-CBC.
* display interface: SPI serial bus operating up to 20 MHz.
* button interface: RTC GPIO input configured with a callback on negative edge triggers.

## Program Flow Table

| Step | State/Action | Condition / Input | Output / State Transition |
|---|---|---|---|
| 1 | Boot Wake | Power-on, Button, or Timer interrupt | Reads RTC registers. If wake cause is timer, sends heartbeat and sleeps. If button / power-on, initialises subsystems and displays Welcome screen. |
| 2 | Active Welcome Screen | Subsystems initialised | Displays "Tap or Press to Board". PN532 enters Target mode (TgInitAsTarget). Resets 30-second idle timer. |
| 3 | NFC Tap (Primary) | Master taps PN532 — TgInitAsTarget activates | Receives NFC_BOARD_CMD (6 bytes). Looks up fare_id in dictionary. Sends NFC_ACK. Triggers execute boarding process. |
| 4 | Command RX (ESP-NOW) | Receives TOMS_MSG_BOARD_COMMAND on ESP-NOW | Validates target UID. If matched, sends ACK and triggers execute boarding process. |
| 5 | Boarding Execution | Valid command payload | Shows "Processing..." screen (0.5s), displays Fare and Seat screen (3.0s), generates and renders QR Receipt screen (8.0s). |
| 6 | Boarding Completion | Renders QR screen | Sends TOMS_MSG_PASSENGER_BOARD packet to Master via ESP-NOW (Phase 2 confirmation). Re-displays Welcome screen. Resets idle timer. |
| 7 | Manual Button Request | Button pressed (short press) | Transmits TOMS_MSG_BUTTON_PRESS to Master via ESP-NOW. Shows "Processing..." screen. Waits up to 5s for response. |
| 8 | Button Request Response | Received response within 5s | Executes boarding process immediately. |
| 9 | Button Request Timeout | No response within 5s | Displays "Master Timeout" error screen (3.0s) and returns to Welcome screen. |
| 10 | Debug Long Press | Button long-pressed for 500ms | Enters Debug mode. Generates and displays a mock printable receipt. |
| 11 | Debug Screen Progression | Short button press in debug receipt screen | Generates receipt string and renders the equivalent QR code. |
| 12 | Debug Exit | Short button press in debug QR screen | Exits debug mode, returns to Welcome screen. |
| 13 | Idle Timeout Sleep | 30 seconds of inactivity | Displays Sleep screen (blacks screen, turns off LCD backlight) and enters deep sleep. |

## Program Flowchart

```mermaid
flowchart TD
    Wake[Wake Up / Reset] --> Get_Cause{Get Wake Cause}
    Get_Cause -->|Timer Wake| Send_Hb[Send ESP-NOW Heartbeat] --> Sleep[Enter Deep Sleep]
    Get_Cause -->|Button / Power| Init[Initialize Subsystems] --> Show_Welcome[Show Welcome Screen]
    
    Show_Welcome --> Active_Loop[Main Active Loop]
    
    Active_Loop -->|NFC Tap| NFC_Rx[Receive NFC_BOARD_CMD]
    NFC_Rx --> Dict_Lookup[Look up fare_id in Dictionary]
    Dict_Lookup --> NFC_ACK[Send NFC_ACK] --> Boarding
    
    Active_Loop -->|ESP-NOW BOARD_COMMAND| UID_Check{Target UID Matches?}
    UID_Check -->|No| Drop_Cmd[Drop Packet] --> Active_Loop
    UID_Check -->|Yes| Boarding[Execute Boarding Flow: Show Fare, Render QR Code, Tx Passenger Event via ESP-NOW] --> Show_Welcome
    
    Active_Loop -->|Short Button Press| Btn_Request[Tx BUTTON_PRESS to Master]
    Btn_Request --> Show_Proc[Show Processing Screen]
    Show_Proc --> Wait_Response{Wait for response up to 5s}
    Wait_Response -->|Rx BOARD_COMMAND| Boarding
    Wait_Response -->|Timeout| Show_Err[Show Master Timeout Error] --> Show_Welcome
    
    Active_Loop -->|Long Button Press 500ms| Debug_Receipt[Show Mock Debug Receipt Screen]
    Debug_Receipt -->|Short Button Press| Debug_QR[Show Debug QR Receipt Screen]
    Debug_QR -->|Short Button Press| Show_Welcome
    
    Active_Loop -->|30s Inactivity| Show_Sleep[Show Sleep Screen & Turn Off Screen] --> Sleep
```

## APIs in the Codebase

### Implemented APIs

* `int toms_display_init(void)`: Configures SPI bus pins, registers display panel driver, initializes LVGL framework buffers.
* `void toms_display_set_backlight(uint8_t brightness)`: Adjusts backlight brightness level using LEDC PWM.
* `int toms_button_init(void)`: Configures button GPIO with internal pull-up and attaches ISR callback on falling edge.
* `void toms_button_set_callback(toms_button_cb_t cb)`: Registers the application event handler for button transitions.
* `void toms_button_task(void *arg)`: FreeRTOS task handling button state debouncing and long-press detection.
* `void toms_sleep_init(void)`: Configures ext0 wake-up sources and RTC wake timer intervals.
* `void toms_sleep_enter(void)`: Disables display backlight and triggers deep sleep mode.
* `toms_wake_cause_t toms_sleep_get_wake_cause(void)`: Returns the enum mapping for the wake-up trigger.
* `void toms_ui_show_welcome(void)`: Switches to Welcome prompt screen.
* `void toms_ui_show_processing(void)`: Displays spinner indicating master communication.
* `void toms_ui_show_fare(const char *route_name, uint16_t fare_centavos, uint8_t seat_number)`: Renders boarding details.
* `void toms_ui_show_qr(const char *qr_data)`: Renders QR code receipt.
* `int toms_slave_nfc_init(void)`: Initializes PN532 over I2C as NFC-DEP Target. Loads eFuse MAC into NFCID3. Loads fare dictionary from NVS.
* `void toms_slave_nfc_set_board_cb(toms_slave_nfc_board_cb_t cb)`: Registers callback for boarding commands received via NFC tap.
* `void toms_slave_nfc_task(void *arg)`: NFC Target listener task. Waits for Master tap (IRQ-driven), receives compact command, expands via fare dictionary, fires callback.
* `esp_err_t toms_fare_dict_load(toms_fare_dict_t *dict)`: Loads fare dictionary from NVS.
* `const toms_fare_entry_t *toms_fare_dict_lookup(const toms_fare_dict_t *dict, uint8_t fare_id)`: Fare entry lookup by ID.

### Planned to be Implemented

* `bool toms_config_load_from_nvs(void)`: Planned API to read stored route IDs and seat numbers on startup.
* `bool toms_config_save_to_nvs(const toms_config_payload_t *cfg)`: Planned API to update configuration parameters.
* `bool toms_fare_table_save_to_nvs(...)`: Planned API to store fare table updates in NVS.

## Planned / Implemented User Acceptance Testing (UAT)

1. NFC Tap Boarding: Master taps the Slave. The Slave must receive the compact NFC_BOARD_CMD, look up the fare in its dictionary, display the fare screen, render the QR code, send ESP-NOW confirmation, and return to Welcome. Total time from tap to fare screen: < 500ms.
2. Local Debug Receipt: Long press the physical button for 500ms. The display must render the mock receipt page. Click the button; it must transition to the QR code. Click again; it must return to the Welcome screen.
3. Anti-fraud UID Validation: Send a wireless `BOARD_COMMAND` with a mismatched target UID. The Slave must silently discard the command and remain in Welcome state.
4. Button-triggered Boarding: Click the button on the Welcome screen. The device must send a button press packet and display "Processing...". The Master must reply, and the Slave must transition to boarding screens.
5. Inactivity Sleep: Leave the Slave untouched. The screen backlight must turn off and the unit enter deep sleep after 30 seconds.

## Testing and Validation (Hardware Focus: Module & Power Testing)

### Power Measurement and Calibrations
* Active Consumption: Peripherals (TFT LCD backlight, CPU running at 240 MHz, PN532 NFC) consume approximately 70 - 90 mA.
* Deep Sleep Optimization: CPU cores are powered down, Wi-Fi RF is disabled, LCD is put into sleep mode, PN532 enters power-down. Deep-sleep current under 15 microamps.
* Wake-up Calibrations: RTC controller detects button presses (GPIO 4 falling edge) via `esp_sleep_enable_ext0_wakeup`.

### Module Interface Verification
* SPI LCD Clock Rate: The SPI bus operates at 20 MHz.
* PN532 I2C Communication: I2C bus at 400 kHz on GPIO 2 (SDA) / GPIO 3 (SCL). IRQ on GPIO 5 for zero-latency response detection.
* NFC-DEP Target Mode: PN532 configured for DEP-only mode. NFCID3 embeds the Slave's eFuse MAC for identification during link setup.
* Debouncing Calibration: A debouncing task (50ms interval) reads raw pin values and verifies stable levels.

## Potential TODOs in the Codebase

1. Load configurations from NVS: Implement NVS loading to configure default variables like seat assignments on startup.
2. Persist Fare Tables: Implement logic to save received fare tables locally to NVS via `toms_fare_dict_save()`.
3. Dynamic Backlight Timeout: Dynamically scale down backlight brightness after 15 seconds of idle time before entering sleep.

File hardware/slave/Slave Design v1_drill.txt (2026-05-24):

; NON-PLATED HOLES START AT T1
; THROUGH (PLATED) HOLES START AT T100
M48
INCH
T1C0.125984
T100C0.038000
T101C0.035000
T102C0.069562
T103C0.040000
%
T1
X020890Y002744
X009861Y002744
X009851Y023204
X020890Y023204
T100
X009579Y020499
X003578Y014494
X002578Y014494
X017999Y023405
X014999Y023405
X006578Y014494
X015000Y002550
X005578Y014494
X005579Y020499
X003579Y020499
X018999Y023405
X016999Y023405
X012999Y023405
X015999Y023405
X008579Y020499
X009578Y014494
X013999Y023405
X006579Y020499
X002579Y020499
X008578Y014494
X014000Y002550
X016000Y002550
X001580Y020499
X004578Y014494
X001579Y014494
X007579Y020499
X004579Y020499
X007578Y014494
X017000Y002550
X011999Y023405
T101
X002000Y010555
X006000Y010555
T102
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

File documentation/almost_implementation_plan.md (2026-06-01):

# TOMS — Final Implementation Plan
### Informed by: Survey Synthesis Report (n=20) + SLR Chapter II (22 Primary Studies)

> [!IMPORTANT]
> **TOMS = Transportation *Occupancy* Monitoring System.**
> Occupancy is the primary output. Every other feature — fare calc, GPS, alarms, dashboard — exists to make occupancy data accurate and automatic.

---

## I. SLR Literature Analysis (TOMS.txt — Chapter II)

This section maps the 22-study Systematic Literature Review (PRISMA, 2020–2026) directly to TOMS design decisions, and explicitly verifies where TOMS aligns with or improves upon the literature.

---

### A. Literature Challenges & TOMS Solutions

#### Challenge 1 — Inaccurate Real-Time Passenger Manifests
> *"Basic IR and ultrasonic sensors struggle with precision when passengers move in close proximity at the doorway" (Haque et al., 2024; Murdan et al., 2020)*

**TOMS approach:** Avoids sensor-based entry/exit detection entirely. Instead, **NFC tap = boarding event**. The conductor physically assigns a slave device to each passenger — this is the manifest. No false positives, no crowding errors. 100% intentional-tap accuracy, matching S21's dual-verification outcome without the fixed-gate infrastructure.

> **Alignment:** Surpasses IR/ultrasonic approaches from S3, S4, S14. Matches the "reusable seat-marker" gap identified in Section 2.3.3.

---

#### Challenge 2 — Connectivity and Synchronization in Dead Zones
> *"Most standard IoT architectures fail to synchronize data effectively when a vehicle enters a cellular signal dead zone" (Kulange et al., 2025; Nirmala et al., 2024)*

**TOMS approach — Real-time first, cache as fallback:**

```
Event occurs (NFC tap / payment / alarm)
        │
        ▼
  Internet available?
    YES ──► POST to server immediately (real-time occupancy)
    NO  ──► Write to local SQLite queue (synced = 0)
                    │
                    ▼
          Internet restored?
            YES ──► Flush SQLite queue (oldest first) + continue real-time
            NO  ──► Keep caching, retry every 30s
```

- **ESP-NOW** (2.4 GHz P2P) — always works between master and slaves, internet irrelevant
- **Real-time path:** HTTP POST each event to server as it happens (when signal available)
- **Cache path:** SQLite `passenger_logs` with `synced = 0` flag — already in the schema
- **Auto-flush:** `SyncService` watches connectivity, drains queue when internet returns, sends all cached + marks `synced = 1`
- **SPIFFS on master** — secondary backup if phone itself disconnects from master
- **Result:** Dashboard is live when signal exists; catches up automatically when it returns

> **Alignment:** Extends S17 (Kulange) offline-first with real-time push layer. Matches S22 (Vadivel) cloud-based monitoring goal. Directly addresses dead zones at Tag-ibo, Sta. Fe, Barinaut, Timoga.

---

#### Challenge 3 — Portability and Hardware Robustness
> *"Many designs are structurally intended for large, stationary bus terminals rather than compact, mobile units" (Bhavani et al., 2025)*

**TOMS approach:** The master is a handheld ESP32-S3 device carried by the conductor. Slave devices are small battery-powered units passed to passengers. No fixed infrastructure required. Matches "portable handheld POS" gap from Section 2.3.3.

> **Alignment:** Directly addresses the research gap: *"a unified handheld POS that integrates automatic passenger counting... features currently confined to fixed gate infrastructure."*

---

#### Challenge 4 — High Initial Cost and Operator Resistance
> *"Small-scale operators are often resistant to upfront costs, preferring traditional manual collection" (Murdan et al., 2020; Zaman et al., 2023)*

**TOMS approach:**
- Uses ESP32 (weighted score **4.70** in Table 2.10 — highest of all platforms evaluated)
- ESP32 chosen for: dual-core 240MHz, native Wi-Fi/BT, low power, low cost (~$5/unit)
- No proprietary hardware, no cloud subscription required for basic operation
- Reusable slave devices replace single-use paper tickets — **cost reduces over time**

> **Alignment:** ESP32 selection matches the literature's consensus (S7, S14, S15, S17, S18, S19, S21 all use ESP32). Dashboard Option A (static JSON) requires zero server costs.

---

#### Challenge 5 — Data Security and Fare Transparency
> *"RFID card cloning, unauthorized database access, and fraudulent transactions remain concerns" (Iswarya et al., 2022; Kulange et al., 2025)*

**TOMS approach:**
- **eFuse MAC as UID** — hardware-burned, impossible to clone without physical access
- **AES-256 encryption** on ESP-NOW payloads (`toms_crypto` module, already implemented)
- **Anti-fraud UID validation** in slave firmware: board commands with wrong `target_uid` are silently dropped
- **Immutable SQLite log** on phone: each tap event timestamped and stored permanently
- **QR receipt** on slave screen: passenger has photographic proof

> **Alignment:** Matches S16's "Device ID Lock," S18's offline anti-malpractice storage, and S21's dual-verification fraud prevention.

---

### B. Literature Research Gaps & TOMS Responses

| Gap Identified in Literature | TOMS Solution |
|---|---|
| No unified handheld POS combining fare + counting | Master device = POS + NFC tap = count. Single unit. |
| Reusable seat-based markers (not personal cards) | Slave devices ARE the reusable markers. Returned after use. |
| Offline-first logic for dead zones | ESP-NOW + SQLite + SPIFFS. Zero cloud dependency during transit. |
| Solutions tailored for "konduktor-led" PUV ops | Entire workflow designed around conductor's actual process. |
| Low-cost open-source for local minibus ops | ESP32 (~$5), open firmware, no licensing fees. |

---

### C. Occupancy — Does TOMS Align with the Literature?

**YES — and it fills the gap the literature couldn't.**

The SLR found that occupancy monitoring in existing systems uses:
- **IR/ultrasonic sensors** at doorways (S3, S4, S14) — error-prone in crowded boarding
- **ESP32-CAM + FOMO ML** (S19, Gonzales et al.) — 95.3% seat precision, but requires camera hardware
- **Optical-RFID dual-verification** (S21, Lam et al.) — 100% accuracy but fixed gate infrastructure only

**The gap the literature explicitly names (Section 2.3.3):**
> *"A significant void exists regarding reusable, seat-based RFID markers which are more practical for high-turnover public utility vehicles than individual smart card ownership."*

**TOMS fills this gap exactly:**

| Literature Method | TOMS Method |
|---|---|
| IR sensor counts everyone through a door | NFC tap assigns a device — only boarded passengers are counted |
| Camera detects if seat is empty/occupied | Slave device state (ACTIVE/PAID) IS the occupancy state |
| Fixed gate dual-verification | Mobile: conductor taps slave → automatic boarding record |
| Personal RFID card owned by passenger | Reusable slave device — owned by operator, returned each trip |
| Seat occupancy as a count | Occupancy = `slavesDeployed / maxCapacity` (real-time, per-bus) |

**The TOMS occupancy model is not just aligned — it represents the specific solution the literature calls for but no prior study implemented.** The slave device is simultaneously: the reusable marker, the receipt terminal, the payment button, and the occupancy counter.

---

### D. Hardware Alignment with Literature (Table 2.9 / 2.10)

| Criterion | Literature Winner | TOMS Choice | Score |
|---|---|---|---|
| Processing Power | ESP32 | ESP32-S3 (faster) | ✅ |
| IoT Connectivity | ESP32 | ESP32-S3 (Wi-Fi + BT + ESP-NOW) | ✅ |
| Power Efficiency | ESP32 | ESP32-S3 (deep sleep on slave) | ✅ |
| I/O & Memory | ESP32 | ESP32-S3 (more GPIO, PSRAM) | ✅ |
| Cost & Scalability | Arduino (cheapest) | ESP32-S3 (slightly higher but justified) | ✅ |

---

## II. Survey Problem Analysis & TOMS Solutions

The following maps each of the 7 identified field problems directly to TOMS features.

---

### Problem 1 — Inaccurate Passenger Counting
> *80% of conductors rely solely on memory or visual estimation*

**Root cause:** No physical record of boarding. A passenger could board, ride, and alight without being counted if the conductor is busy with another passenger.

**TOMS Solution:**
- Every passenger is assigned a **slave device** via NFC tap — this is the count. If no tap, no count, no ride.
- The master stores a `PASSENGER_BOARD` ESP-NOW event for each tap, logged to SPIFFS immediately.
- The conductor's phone shows a **real-time passenger count** in the active sessions panel — visible at a glance even during peak hours.
- The company dashboard shows ridership per trip, per route, per time-of-day — replacing memory with data.

---

### Problem 2 — Fare and Change Computation Errors
> *85–90% agree that managing exact change and fare tracking is a daily struggle*

**Root cause:** Conductors compute fares mentally while multitasking. Large bills create change-management stress.

**TOMS Solution:**
- Fare is **auto-calculated by the app** (zone-based stop pair → fare dict lookup). Conductor selects origin/destination → fare appears instantly. Zero mental math.
- The slave device **displays the fare on screen** — passenger sees the exact amount. No verbal disagreement possible.
- Discount types (Regular / Student / PWD / Senior) are selected in the app — discount is applied automatically, shown on receipt.
- **Change computation helper:** When conductor taps "collect payment", the app shows a change calculator: enter tendered amount → change displayed. Optional feature for Phase 2.

---

### Problem 3 — Cash-to-Passenger Count Mismatch
> *80% confirm daily discrepancy between cash collected and passenger count*

**Root cause:** Paper tickets can be lost or skipped. No link between physical ticket and collected cash.

**TOMS Solution:**
- Every transaction generates a **digital log entry** (timestamp, fare, slave UID, route, passenger type) stored locally in SQLite on the phone.
- The **company dashboard** receives these logs via USB sync or Wi-Fi when the bus returns to terminal — showing exact expected revenue vs actual per trip.
- End-of-day reconciliation is no longer manual: TOMS generates an automatic **shift report** with total passengers, total expected revenue, and breakdown by passenger type.

---

### Problem 4 — Disputed Transactions with No Audit Trail
> *2–3 disputes per conductor per week; no objective resolution possible*

**Root cause:** Paper tickets can be discarded. Verbal-only transactions leave no evidence.

**TOMS Solution:**
- Every `PASSENGER_BOARD` event is stored with: timestamp, slave UID, fare, route, seat number, boarding stop.
- The slave device generates a **QR receipt** — passenger can photograph it as proof.
- The company dashboard has a **transaction search** — any disputed fare can be looked up by time range or UID.
- The slave device shows the receipt on screen until the passenger dismisses it — no physical ticket to lose.

---

### Problem 5 — Environmental Waste from Paper Tickets
> *90% agree paper tickets produce litter*

**Root cause:** Single-use paper tickets issued per passenger per trip.

**TOMS Solution:**
- Slave devices **are the ticket** — reusable, returned to the conductor after alighting.
- No paper is produced. Receipt is digital (QR on screen).
- The company owns a pool of slave devices shared across trips.
- **Environmental impact quantifiable:** TOMS can report "paper tickets replaced" count on the dashboard — useful for thesis and reporting.

---

### Problem 6 — Offline-Only Operational Environment
> *80% report dead zones: Tag-ibo, Sta. Fe, Barinaut (Dalipuga); Timoga (Buru-un)*

**Root cause:** Routes pass through forested/rural areas with zero cellular signal.

**TOMS Solution (already designed for this):**
- **ESP-NOW** — no internet, no Wi-Fi infrastructure needed. 2.4 GHz peer-to-peer between master and slaves, works anywhere.
- **NFC** — short-range, completely offline.
- **SQLite on phone** — all transactions stored locally. No cloud write during operation.
- **SPIFFS on master** — backup log storage if phone disconnects.
- **Dashboard sync:** When the bus returns to terminal (Wi-Fi available), the app uploads all pending logs automatically. The dashboard shows a "pending sync" badge until this completes.
- The system is **100% functional with zero network** during route operation.

---

### Problem 7 — Manual End-of-Day Reconciliation
> *DONSALS: office staff travels to each bus at 6 PM to collect tickets and cash*

**Root cause:** No digital record. Physical ticket collection is the only audit mechanism.

**TOMS Solution:**
- At end of shift, conductor connects phone to terminal Wi-Fi (or plugs into office PC via USB).
- App auto-uploads all unsynced logs to the company server.
- Company dashboard instantly shows the shift summary: passengers, revenue, route, discounts, unpaid fares.
- **The 6 PM office visit becomes unnecessary.** Reconciliation is done in seconds from any browser.
- Office staff can review each bus's data remotely in real time when any Wi-Fi is available.

---

## II. Confirmed Architecture Decisions

| Decision | Confirmed Choice |
|---|---|
| GPS source | Phone GPS (Option A) |
| Session management | Flutter AppState / phone (Option A) |
| Fare calculation | Zone-based stop pairs (Option B) + GPS auto-detects boarding point A |
| Discounts | Regular / Student / PWD / Senior Citizen |
| Boarding UI | Both sequential (quick) + queue (multi-passenger) |
| Proximity alarm | Phone GPS geofencing, 200m threshold (Option A) |
| Offline operation | 100% — ESP-NOW + SQLite + SPIFFS, sync when Wi-Fi available |
| Firmware changes | Minimal (Phase 4 only: slave alarm command) |
| **Occupancy model** | **No fixed seats. Occupancy = slaves currently deployed ÷ bus max capacity. Slot number (1, 2, 3…) assigned dynamically when slave is handed to a passenger.** |

---

## III. System Components

```
┌──────────────────────────────────────────────────────────────┐
│              COMPANY DASHBOARD (Web — browser)               │
│  Real-time fleet view, shift reports, audit trail, analytics │
│  Served from: Node.js or simple Python backend on office PC  │
│  Or: Static JSON export viewed in a local web app            │
└───────────────────────┬──────────────────────────────────────┘
                        │ Wi-Fi / USB sync (end of shift)
┌───────────────────────▼──────────────────────────────────────┐
│              FLUTTER APP (Conductor's Phone)                  │
│  Session mgmt • GPS • Fare calc • Proximity alarm            │
│  Offline SQLite log • Sync service                           │
└───────────────────────┬──────────────────────────────────────┘
                        │ USB CDC (always connected in-trip)
┌───────────────────────▼──────────────────────────────────────┐
│              ESP32 MASTER                                     │
│  NFC-DEP initiator (PN532) • ESP-NOW hub • SPIFFS backup    │
└────────────┬──────────────────────────────┬──────────────────┘
       NFC tap                          ESP-NOW
┌───────────▼──────────┐    ┌────────────▼──────────────────┐
│  SLAVE (NFC Target)  │    │  SLAVE (Button Press / Board) │
│  Shows QR receipt    │    │  PASSENGER_BOARD confirm      │
└──────────────────────┘    └───────────────────────────────┘
```

---

## IV. Occupancy Model

Minibuses (jeepneys) do **not** have assigned seat numbers. Passengers sit anywhere available. Occupancy is therefore defined by:

- **`maxCapacity`** — the physical maximum passengers the bus can hold (configured once per bus, e.g. 20). Stored in `assets/vehicles.json`.
- **`slavesDeployed`** — number of slave devices currently handed out and active in this trip.
- **`occupancyRate`** = `slavesDeployed / maxCapacity`

Each slave gets a **dynamic slot number** (1, 2, 3…) assigned in the order the conductor hands it out — not tied to any physical seat. This slot number is what appears on the receipt and in the app as a short passenger identifier.

### Slot Number vs Seat Number

| Old (wrong) | New (correct) |
|---|---|
| `seat_number` = fixed physical seat | `slot_number` = Nth passenger boarded this trip |
| Stored in slave NVS | Assigned by master at BOARD_COMMAND time |
| E.g. "Seat 3" always means row 1 right | E.g. "#3" means the 3rd passenger who boarded |

The `seat_number` field in `toms_board_command_t` is **reused** as `slot_number`. No firmware struct change needed — only the semantics change.

### Passenger States
```
ACTIVE    → BOARD_COMMAND sent, receipt on slave screen, payment pending
PAID      → passenger pressed button, fare collected, slave returned
ALARMING  → proximity alarm triggered, still unpaid
```

### Occupancy Flow
```
Trip starts. Bus has 0 slaves deployed. Capacity = 20.

Passenger 1 boards:
    Conductor fills BoardingSheet (dest + type)
    → Assigns slot_number = 1 (auto-incremented)
    → Taps slave via NFC
    → BOARD_COMMAND: slot=1, fare=₱13.00, dest=Country Hills
    → Slave shows: "#1 · Country Hills · ₱13.00"
    → App: slavesDeployed = 1  →  Occupancy: 1/20 (5%)

Passenger 2 boards:
    → slot_number = 2
    → slavesDeployed = 2  →  Occupancy: 2/20 (10%)

Passenger 1 presses button (ready to pay):
    → BUTTON_PRESS ESP-NOW → master → USB "button_press"
    → App matches UID → marks slot 1 as PAID
    → Conductor collects fare, retrieves slave
    → slavesDeployed stays 2 until slave is re-assigned
    → App: 1 paid, 1 unpaid

GPS within 200m of Country Hills:
    → Slot 2 still unpaid → state = ALARMING
    → App banner + vibration
```

### `PassengerSlotState` enum (Flutter)
```dart
enum PassengerSlotState { active, paid, alarming }

extension PassengerSlotStateX on PassengerSlotState {
  Color get color => [
    const Color(0xFFFF9F43),   // active   → orange
    const Color(0xFF2ED573),   // paid     → green
    const Color(0xFFFF6B6B),   // alarming → red
  ][index];
  String get label => ['Unpaid', 'Paid', 'ALARM'][index];
}
```

### `OccupancySnapshot` (for dashboard sync)
```dart
class OccupancySnapshot {
  final String vehicleId;
  final DateTime timestamp;
  final int maxCapacity;          // configured max (e.g. 20)
  final int slavesDeployed;       // currently handed out
  final int paidCount;
  final int unpaidCount;
  final int alarmingCount;
  double get occupancyRate => slavesDeployed / maxCapacity;
  final List<PassengerSlot> slots;
}

class PassengerSlot {
  final int slotNumber;           // 1-based, order boarded
  final String slaveUid;          // eFuse MAC
  final PassengerSlotState state;
  final String destination;
  final int fareCentavos;
  final PassengerType passengerType;
  final DateTime boardedAt;
}
```

---

## V. Data Models

### `PassengerType` enum
```dart
enum PassengerType { regular, student, pwd, senior }

extension PassengerTypeX on PassengerType {
  String get label => ['Regular', 'Student', 'PWD', 'Senior'][index];
  double get multiplier => [1.0, 0.80, 0.80, 0.80][index];
}
```

### `TransitStop`
```dart
class TransitStop {
  final int id;
  final String name;
  final double lat;
  final double lon;
}
```
Loaded from `assets/stops.json` at startup.

### `PassengerSession`
```dart
class PassengerSession {
  final String id;              // UUID
  final String slaveUid;        // eFuse MAC of assigned slave
  final TransitStop boarding;
  final TransitStop destination;
  final int fareId;
  final int baseFareCentavos;
  final int finalFareCentavos;  // after discount
  final PassengerType type;
  final DateTime boardedAt;
  bool paid;
  bool alarmTriggered;
}
```

### `PendingPassenger` (Queue mode)
```dart
class PendingPassenger {
  final String id;
  final TransitStop boarding;
  final TransitStop destination;
  final int fareId;
  final int fareCentavos;
  final PassengerType type;
  final DateTime queuedAt;
}
```

### `PassengerLog` (updated)
```dart
// New fields added:
final int passengerType;        // PassengerType.index
final int discountCentavos;
final String boardingStop;
final String destinationStop;
final double destinationLat;
final double destinationLon;
```

### `DeviceStatus` (updated)
```dart
// Rename: uartState → nfcState
// Parse: json['nfc_state'] instead of json['uart_state']
final int nfcState;
```

### `ShiftReport` (new — for dashboard sync)
```dart
class ShiftReport {
  final String vehicleId;
  final String routeName;
  final DateTime shiftStart;
  final DateTime shiftEnd;
  final int totalPassengers;
  final int totalRevenueCentavos;
  final int regularCount;
  final int studentCount;
  final int pwdCount;
  final int seniorCount;
  final int discountTotalCentavos;
  final List<PassengerLog> transactions;
}
```

---

## V. Database Schema

**Version bump: `v1` → `v2`**

```sql
-- Migration from v1 to v2
ALTER TABLE passenger_logs ADD COLUMN passenger_type    INTEGER DEFAULT 0;
ALTER TABLE passenger_logs ADD COLUMN discount_centavos INTEGER DEFAULT 0;
ALTER TABLE passenger_logs ADD COLUMN boarding_stop     TEXT    DEFAULT '';
ALTER TABLE passenger_logs ADD COLUMN destination_stop  TEXT    DEFAULT '';
ALTER TABLE passenger_logs ADD COLUMN destination_lat   REAL    DEFAULT 0;
ALTER TABLE passenger_logs ADD COLUMN destination_lon   REAL    DEFAULT 0;
```

---

## VI. New Assets

### `assets/stops.json`
```json
[
  {"id":1, "name":"DPWH - Tambo Terminal",       "lat":8.2287, "lon":124.2451},
  {"id":2, "name":"Country Hills",               "lat":8.2456, "lon":124.2611},
  {"id":3, "name":"Brgy. Burul",                 "lat":8.2378, "lon":124.2534},
  {"id":4, "name":"Tag-ibo",                     "lat":8.1912, "lon":124.2133},
  {"id":5, "name":"Dalipuga Terminal",            "lat":8.1756, "lon":124.2089}
]
```
Operator populates the actual coordinates before deployment.

---

## VII. Services (Flutter)

| Service | Role |
|---|---|
| `StopService` | Loads stops.json, finds nearest stop to GPS coords |
| `SessionService` | Active sessions + pending queue + fare calc + discount |
| `GpsService` | Streams phone position every 5s |
| `ProximityService` | Monitors sessions, fires alarm at < 200m to destination |
| `SyncService` | **Real-time POST when online; SQLite cache queue when offline; auto-flush on reconnect** |
| `ConnectivityService` | Watches internet state (via `connectivity_plus`), notifies `SyncService` |
| `UsbService` | (Modified) NFC events + button_press → session markPaid |
| `AppState` | Orchestrates all services |

### `SyncService` — Detailed Behaviour

```dart
class SyncService {
  // Called after every boarding event, payment, or alarm
  Future<void> push(OccupancyEvent event) async {
    // 1. Save to SQLite immediately (synced = 0)
    await _db.insertEvent(event);

    // 2. If online — try to POST now
    if (_connectivity.isOnline) {
      await _trySendNow(event);
    }
    // If offline — leave in queue, ConnectivityService will flush
  }

  // Called by ConnectivityService when internet is restored
  Future<void> flushQueue() async {
    final pending = await _db.getUnsynced();   // synced = 0, ordered ASC
    for (final event in pending) {
      final ok = await _trySendNow(event);
      if (!ok) break;                          // stop on failure, retry next cycle
    }
  }

  // Retry every 30 seconds while offline
  void startRetryTimer() {
    Timer.periodic(Duration(seconds: 30), (_) {
      if (_connectivity.isOnline) flushQueue();
    });
  }
}
```

**What is pushed to the server on each event:**
```json
{
  "event_type": "board",          // board | payment | alarm | release
  "timestamp": "2026-05-26T21:05:33+08:00",
  "vehicle_id": "CDB-001",
  "route": "Dalipuga",
  "slot_number": 3,
  "slave_uid": "A1B2C3D4E5F6",
  "passenger_type": "senior",
  "fare_centavos": 1040,
  "discount_centavos": 260,
  "boarding_stop": "DPWH Terminal",
  "destination_stop": "Country Hills",
  "occupancy_now": 14,             // slavesDeployed at time of event
  "max_capacity": 20
}
```

This payload lets the dashboard **reconstruct exact occupancy state at any point in time** — even if the bus was offline for part of the trip — by replaying events in timestamp order.

**Connectivity state indicator in UI:**
```
  🟢 Online   — events sent live to dashboard
  🟡 Caching  — N events queued, will sync on reconnect
  🔴 No USB   — master disconnected
```

### Discount Calculation
```dart
int calculateFare(int baseFareCentavos, PassengerType type) {
  return (baseFareCentavos * type.multiplier).ceil();
}
int calculateDiscount(int baseFareCentavos, PassengerType type) {
  return baseFareCentavos - calculateFare(baseFareCentavos, type);
}
```

Philippine law reference:
- Senior Citizen: 20% discount (RA 9994, Expanded Senior Citizens Act)
- PWD: 20% discount (RA 10754)
- Student: 20% discount (subject to LGU/LTFRB resolution per route)

---

## IX. Screens (Flutter App)

### Modified: `DashboardScreen`
- NFC badge: "NFC ACTIVE" / "NFC IDLE" (replaces DOCKED)
- NFC state item (replaces UART)
- **Occupancy bar + passenger slot cards** (primary feature)
- FAB → "**+ Passenger**" (opens `BoardingSheet`)

### New: `OccupancyPanel` (embedded in Dashboard, main widget)

No grid/seat map — just a capacity bar and a list of active passenger slot cards:
```
  CDB-001 · Dalipuga Route
  ┌────────────────────────────────────────────┐
  │ Occupancy  ████████████░░░░░░░░  14 / 20  │
  │            Unpaid: 3   Paid: 11   70%      │
  └────────────────────────────────────────────┘

  ACTIVE PASSENGERS
  ┌──────────────────────────────────────────────────┐
  │ 🔴 #7   Country Hills   ₱10.40  Senior   ALARM  │ ← pulsing
  │ 🟠 #3   Brgy. Burol     ₱13.00  Regular  UNPAID │
  │ 🟠 #5   Tambo Terminal  ₱ 9.00  PWD      UNPAID │
  │ ✅ #1   Country Hills   ₱10.40  Senior   PAID   │
  │ ✅ #2   Brgy. Burol     ₱13.00  Student  PAID   │
  └──────────────────────────────────────────────────┘

  [ + New Passenger ]   Revenue today: ₱271.80
```

- Each row is a `PassengerSlot` card — tapping it expands to show:
  - Boarding stop, destination, boarded time
  - Fare breakdown (base + discount)
  - [Mark Paid] button (manual override if button press missed)
  - [Release Slave] button (when passenger alights, frees the slot)
- `#N` slot number = order boarded, resets each trip
- Capacity bar fills as more slaves are deployed
- ALARMING slots pulse red via `AnimationController`
- No seat grid, no `vehicles.json` layout config needed

### New: `BoardingSheet` (Modal bottom sheet, 2 tabs)

**Tab 1 — Quick (Sequential)**
```
Boarding Point
  ○ Auto-GPS: [DPWH Terminal ✓ — detected]
  ○ Manual:   [Select stop ▾]

Destination:  [Country Hills ▾]
Passenger:    [Regular ▾]     → Fare: ₱13.00
                               → Discount: —

[Tap Slave via NFC]
```
- Auto-GPS pre-fills boarding stop from nearest stop to current phone position
- Selecting "Manual" shows the stop picker (searchable list)

**Tab 2 — Queue (Multi-passenger)**
```
Pending Queue
  □ DPWH → Country Hills  ₱13.00  Regular    [Assign →]
  □ DPWH → Brgy. Burol   ₱10.00  Senior ★   [Assign →]

[+ Add Another Passenger]
```
- "Assign →" taps that queue item's slave via NFC
- Multiple passengers can be queued before any slave is assigned

### New: `ActiveSessionsPanel` (on dashboard)
```
ACTIVE PASSENGERS  (3 riding · 2 unpaid)
┌─────────────────────────────────────────────────────┐
│ 🔴 S2  Country Hills    ₱10.40 Senior    UNPAID ⚠  │  ← alarm near
│ 🟡 S1  Brgy. Burol     ₱10.00 Regular   UNPAID    │
│ ✅ S3  Tambo Terminal  ₱ 9.00 Student   PAID      │
└─────────────────────────────────────────────────────┘
```
Each row: tap to expand → shows boarding time, slave UID, change calc

### New: `ProximityAlarmBanner`
```
⚠ UNPAID FARE — 150m to Country Hills
   Slave S2 · ₱10.40 Senior Citizen
                                    [Mark Paid]  [Dismiss]
```
+ Phone vibration + local notification sound

### New: `ShiftSummaryScreen`
Accessible from the overflow menu. Shows end-of-shift stats:
```
SHIFT SUMMARY  —  May 26, 2026

Total Passengers:     23
Total Revenue:        ₱271.80
  Regular:   18 × avg ₱12.30  = ₱221.40
  Student:    3 × avg ₱10.50  = ₱ 31.50
  Senior:     2 × avg ₱ 9.45  = ₱ 18.90
  Discounts given:             = ₱ 15.60

[ Export JSON ]   [ Sync to Dashboard ]
```

---

## IX. Company Dashboard (Web)

A **separate web application** for the transport operator (DATRANSCO / DONSALS office).
Accessed via browser on an office PC or tablet.
Data arrives via: **Wi-Fi JSON upload** from the conductor's phone (when bus returns to terminal) OR **USB file export**.

### Dashboard Screens

#### 1. Fleet Overview (Home) — with Live Occupancy
```
TOMS Fleet Dashboard — DATRANSCO                  May 26, 2026

Active Buses: 3    Fleet Avg Occupancy: 61%    Total Revenue Today: ₱4,230.00

┌──────────┬──────────┬───────────┬──────────────────────┬──────────┬──────────┐
│ Bus ID   │ Route    │ Conductor │ Occupancy            │ Revenue  │ Status   │
├──────────┼──────────┼───────────┼──────────────────────┼──────────┼──────────┤
│ CDB-001  │ Dalipuga │ J. Reyes  │ ████████░░  14/20    │ ₱168.00  │ 🟢 Live  │
│ CDB-002  │ Dalipuga │ R. Santos │ █████░░░░░   9/20    │ ₱109.00  │ 🟡 Sync  │
│ CDB-003  │ Buru-un  │ M. Cruz   │ ████████████ 20/20   │ ₱240.00  │ 🟢 Live  │
└──────────┴──────────┴───────────┴──────────────────────┴──────────┴──────────┘
```
- **Occupancy** = slaves deployed / bus max capacity
- **🟢 Live** = events received in real-time (phone has internet)
- **🟡 N cached** = phone offline, N events queued — occupancy shown is last known state
- Click any row → opens per-bus **passenger slot list** (mirrors conductor's phone panel)
- `20/20` (FULL) highlighted — dispatcher knows to send the next bus
- Occupancy updates immediately as events arrive; no manual refresh needed

#### 2. Transaction Audit Log
- Searchable by: date range, bus, route, passenger type, slave UID
- Replaces the manual 6 PM ticket collection
- Each row: timestamp, bus, route, boarding stop, destination, fare, type, discount, UID
- **Export to CSV** for accounting

#### 3. Revenue Analytics
```
Revenue Trends — Last 7 Days

₱5,000 ┤                              ╭───╮
₱4,000 ┤              ╭──╮           │   │
₱3,000 ┤    ╭──╮     │  ╰──╮       ╭╯   ╰─
₱2,000 ┤───╯  ╰─────╯     ╰──────╯
       Mon   Tue   Wed   Thu   Fri   Sat   Sun

Passenger Type Breakdown:
  Regular  78%   ████████████████████░░░░░
  Student  12%   ████░░░░░░░░░░░░░░░░░░░░░
  Senior    7%   ██░░░░░░░░░░░░░░░░░░░░░░░
  PWD       3%   █░░░░░░░░░░░░░░░░░░░░░░░░
```

#### 4. Dispute Resolution
- Conductor or passenger disputes a fare → office searches by timestamp or UID
- Shows: exact boarding stop, destination, fare computed, passenger type, time
- Resolves the **2–3 weekly disputes** documented in the survey with objective data

#### 5. Reconciliation Report (replaces the 6 PM office visit)
```
End-of-Day Reconciliation — May 26, 2026

Bus CDB-001 (Dalipuga):
  Expected passengers:  23     ✓ Matches TOMS tap count
  Expected revenue:   ₱271.80
  Cash declared:      ₱271.80  ✓ Match
  Discounts applied:  ₱ 15.60  (3 Senior, 2 PWD)
  Status: ✅ BALANCED

Bus CDB-002 (Buru-un):
  Expected passengers:  18
  Expected revenue:   ₱214.50
  Cash declared:      ₱200.00  ⚠ DISCREPANCY: -₱14.50
  Status: ❌ REVIEW REQUIRED
```

### Dashboard Tech Stack Options

| Option | Description | Best For |
|---|---|---|
| **A — Static + JSON** | Flutter app exports a `.json` file; office opens a local HTML dashboard that reads it | Simplest, no server needed, works offline |
| **B — Local server** | Small Node.js or Python FastAPI server on office PC; app POSTs logs via Wi-Fi | Real-time multi-bus view, slightly more setup |
| **C — Cloud** | Firebase / Supabase; app syncs when any internet available | Best scalability, requires data plan |

**Recommendation for thesis/pilot:** Use **Option B** (local Node.js/FastAPI server on the company PC). The real-time sync model requires an HTTP endpoint — Option A (static JSON) cannot receive live pushes. Option B is still LAN-only (no data plan needed), self-hosted, and free. Option C (cloud) is the upgrade path once the pilot is validated.

---

## X. Flutter Packages Required

```yaml
# pubspec.yaml additions
geolocator: ^13.0.1              # Phone GPS
permission_handler: ^11.3.0      # Location + notification permissions
vibration: ^3.1.2                # Haptic alarm
flutter_local_notifications: ^17.2.2  # Audible alarm
share_plus: ^10.0.2              # Export shift JSON / CSV
http: ^1.2.0                     # Real-time event POST + sync queue flush
uuid: ^4.4.0                     # Session ID generation
connectivity_plus: ^6.0.3        # Internet state monitoring (online/offline)
```

---

## XI. Protocol Extension (Firmware, Phase 4 Only)

### New: `TOMS_MSG_ALARM_CMD` (Master → Slave)

Add to `shared_lib/protocol/protocol.h`:
```c
TOMS_MSG_ALARM_CMD = 0x30,

typedef struct __attribute__((packed)) {
    uint8_t  target_uid[16];
    uint8_t  alarm_type;      // 0 = proximity warning, 1 = final stop
    uint8_t  minutes_left;
} toms_alarm_cmd_t;
```

Master USB handler — new command from phone:
```json
{"cmd":"send_alarm", "uid":"A1B2C3D4E5F6", "alarm_type":0, "minutes":2}
```

Slave response: Flash screen red → "Please Pay — 2 min to stop"

---

## XIII. Build Phases

### Phase 1 — NFC + Occupancy Foundation (Flutter only)
- [x] Update `DeviceStatus`: `uartState` → `nfcState`
- [x] Add `PassengerType`, `TransitStop`, `PassengerSession`, `PendingPassenger` to models
- [x] Add `SeatState`, `SeatRecord`, `OccupancySnapshot` to models
- [x] Add `NfcTapEvent` model
- [x] Database v2 migration (add columns)
- [x] `OccupancyService` — seat state table, update from NFC tap + button_press + proximity
- [x] `SessionService` (sessions + queue + fare calc + discounts)
- [x] `UsbService` NFC event handlers (replace dock with nfc/nfc_tap)
- [x] `AppState` wired to OccupancyService + SessionService + button_press → markPaid

### Phase 2 — Occupancy Panel + Boarding UI

> [!NOTE]
> Phase 2a, 2b and 2c are now implemented.

#### 2a — Assets
- [x] `assets/vehicles.json` — created with capacity per bus ID
- [x] `assets/stops.json` ✓ — coordinates confirmed in file

#### 2b — Dashboard UI Changes (dashboard_screen.dart)
- [x] Replace `_StatsRow` with a 3-card row: **Revenue · Passengers · Occupancy %**
- [x] Replace `_DeviceStatusCard` "DOCKED" badge with "NFC ACTIVE / NFC IDLE" badge
- [x] Replace "UART" status item label with "NFC"
- [x] Add `_OccupancyPanel` widget above the transaction list
  - Capacity bar with occupancy rate + color coding (green/orange/red)
  - Unpaid count sub-label
  - Scrollable list of `_PassengerSlotCard` tiles
- [x] `_PassengerSlotCard` — slot badge, destination, fare, type, state chip
  - Tap to expand: boarding stop, boarded time, fare breakdown
  - [Collect Payment] → inline change calculator → [Confirm Paid]
  - [Mark Paid] (skip calculator) + [Release Slave] buttons
  - ALARMING state: pulsing red glow via `AnimationController`
- [x] Replace FAB with **`+ New Passenger`** → opens `BoardingSheet`
  - USB connect/disconnect moved to AppBar overflow menu (⋮)

#### 2c — New Screens / Widgets
- [x] **`boarding_sheet.dart`** (modal bottom sheet, 2 tabs):
  - **Quick tab**: Boarding stop dropdown (GPS hint placeholder for Phase 3) + destination + 4 type chips → live fare preview → [Queue Passenger]
  - **Queue tab**: pending list + per-item [Assign →] manual target + [+ Add Another]
  - [↗ Expand] button → opens `QueueManagerScreen` (full-screen)
- [x] **`queue_manager_screen.dart`** (full-screen queue view):
  - Full pending queue list with slot badges and assign targeting
- [x] **`shift_summary_screen.dart`** (accessible from overflow ⋮ menu):
  - Total revenue, passengers, discounts, peak occupancy
  - Breakdown by passenger type (count + revenue per type)
  - Recent trip log with sync status badges
- [x] **`proximity_alarm_banner.dart`** — blinking overlay, [Mark Paid] + [✕ Dismiss] with confirm dialog, auto-collapses

#### 2d — Session & Occupancy Logic
- [x] Slot number auto-increment in `OccupancyService` — resets to 1 when all sessions clear
- [x] `_PassengerSlotCard` [Release Slave] → `AppState.releaseSlotManual(uid)` — implemented
- [x] `OccupancyService.maxCapacity` loaded from `vehicles.json` via `AppState._init()`

---

#### 2e — POS (Point of Sale) UI

> [!IMPORTANT]
> The full transaction backend is implemented — `SessionService`, `OccupancyService`,
> and `AppState` can calculate fares, assign types, and record logs. However, there is
> **no UI yet** that lets the conductor interact with these. This section tracks those screens.

##### What the Backend Already Supports (ready to wire up)
| Backend capability | Source |
|---|---|
| Fare calculation: `₱13 base + ₱1.80/km` | `SessionService.calculateBaseFare()` |
| Passenger type discounts (Regular / Student / PWD / Senior) | `SessionService.calculateFare()` |
| Stop-pair lookup from `stops.json` | `TransitStop` model — 5 stops loaded |
| Active session list with slot numbers | `OccupancyService.getPassengerSlots()` |
| Mark Paid on a session | `SessionService.markPaid()` / `AppState.markPaidManual()` |
| Release slot (passenger alights) | `SessionService.releaseSlot()` / `AppState.releaseSlotManual()` |
| Pending queue (pre-fill before slave assignment) | `SessionService.pendingQueue` |

##### Design Decisions — Confirmed Answers

> ✅ **Q2 — Boarding stop: CONFIRMED → Option C (auto-GPS with manual override)**
>
> **Expounding on the conductor's role:**
> In a typical minibus (jeepney) operation, the **driver** focuses exclusively on driving and
> route navigation. The **conductor** (konduktor) is the one standing or moving through the
> cabin who:
> - Signals the driver where to stop when a passenger flags the vehicle
> - Physically collects fares and issues tickets/receipts
> - Decides which passengers board and at what stop
>
> Because the conductor is the one who knows the exact boarding location (they just waved
> the driver to stop there), the **auto-GPS is a hint, not a command**. The flow should be:
> 1. GPS silently detects the nearest official stop and pre-fills it (e.g. "DPWH Terminal")
> 2. Conductor glances at the pre-filled stop — if correct, proceeds without touching it
> 3. If the passenger boarded mid-route (not at an official stop), conductor taps the field
>    and manually selects the nearest stop from the dropdown
> 4. The selected stop is what gets logged to the session and sync queue
>
> This keeps boarding fast (1 tap to open form → fare auto-fills → queue) while remaining
> accurate when boarding happens between official stops.

> ✅ **Q3 — Passenger type: CONFIRMED → Option A (button chips, 4 in a row)**
>
> Implementation: `Regular | Student | PWD | Senior` displayed as a segmented button row.
> - Default pre-selected: **Regular**
> - Active chip highlighted with accent color
> - Fare and discount recalculate instantly on chip tap (ties in with Q4)

> ✅ **Q4 — Fare preview: CONFIRMED → Option A (live preview)**
>
> As soon as boarding stop + destination are both selected, fare is computed in real time
> using `SessionService.calculateBaseFare()` and displayed. Changing the passenger type
> chip also instantly updates the displayed fare and discount amount.

> ✅ **Q5 — Change calculator: CONFIRMED → Include now**
>
> A `ChangeCalculatorWidget` will be included in the `ActivePassengerCard` (not the boarding
> form — the conductor collects payment after the passenger is seated, not at boarding).
> - Conductor taps [Collect Payment] on the slot card
> - A number pad / input appears: "Tendered: ₱ ___"
> - App shows: Change = tendered − final fare
> - Confirms [Mark Paid] after conductor enters the amount

> ✅ **Q6 — Assignment mode: CONFIRMED → Both (automatic FIFO + manual override)**
>
> **Default (automatic):** When a slave sends a `button_press` or `nfc_tap` event, the
> app automatically assigns it to the **first item in the pending queue** (FIFO).
> This is the fast path for a single boarding.
>
> **Override (manual):** When there are multiple items in the queue (e.g. 3 passengers
> boarded at once), the conductor can tap a specific queue item in the Queue tab and then
> press [Assign →] — the next slave tap/press is matched to *that* specific queue item
> instead of the FIFO default.
>
> Implementation: `AppState` tracks an `_manualAssignTarget` — if set, the next hardware
> event assigns to that queue item. If null, falls back to FIFO.

> ✅ **Q1 — Where does the POS form live? CONFIRMED → Both**
>
> Both forms will exist and are triggered differently:
>
> | Trigger | Form | Why |
> |---|---|---|
> | FAB **`+ New Passenger`** (single boarding) | **Modal bottom sheet** | Fast, dismissable, dashboard stays visible |
> | Queue tab **`[Expand Queue]`** button | **Full-screen page** | More space to manage multiple pending passengers at once |
>
> **Bottom sheet** (quick/single boarding):
> - Opens from FAB, slides up to ~85% screen height, draggable
> - Conductor fills boarding stop, destination, type → fares preview → [Queue]
> - Swiping down cancels instantly — no navigation needed
> - Dashboard occupancy panel still partially visible behind the sheet
>
> **Full-screen page** (queue management / multi-passenger):
> - Opened via an [Expand ↗] icon on the Queue tab header
> - Shows the full pending queue list + form to add new entries
> - Conductor uses this when multiple passengers board at the same stop
> - Back button / gesture returns to dashboard
> - Better keyboard handling for typing stop names if search is added later

> ✅ **Q7 — Receipt layout on slave screen: CONFIRMED**
>
> **Display specs: 1.8" TFT ST7735 — 128 × 160 px (portrait)**
>
> At typical firmware font sizes on an ST7735:
> - **Small** (`Font6x8`): ~21 chars × 20 rows available
> - **Medium** (`Font8x12`): ~16 chars × 13 rows available
> - **Large** (`Font16x26`): ~8 chars × 6 rows available
>
> Proposed receipt layout (portrait, 128 × 160):
> ```
> ┌────────────────────┐  ← row 0  (y=0)
> │      T O M S       │  large font, centered, accent color
> │  ── Slot  #3 ──    │  medium, centered, white
> ├────────────────────┤  ← divider line  (y≈36)
> │ FROM               │  small, gray label
> │ DPWH-Tambo         │  small, white (truncated to 16 chars)
> │ TO                 │  small, gray label
> │ Country Hills      │  small, white
> ├────────────────────┤  ← divider line  (y≈80)
> │     ₱10.40         │  large font, green/accent
> │  Senior  -₱2.60    │  small, yellow (type + discount)
> ├────────────────────┤  ← divider line  (y≈116)
> │   3 / 20 riders    │  small, gray (occupancy)
> │  [PRESS TO PAY]    │  small, blinking white or accent
> └────────────────────┘  ← y=160
> ```
>
> **Layout rules for firmware:**
> - Total 5 zones: header / route / fare / occupancy / action prompt
> - Stop names truncated to 14 chars max (fits `Font6x8` on 128px width with padding)
> - Fare displayed large — the passenger must be able to read it clearly
> - `[PRESS TO PAY]` blinks at 1Hz to prompt the passenger to press the button
> - Colors: accent/cyan for header, green for fare, yellow for discount, gray for labels
> - After payment confirmed: swap bottom zone to **`✓ PAID  Thank you`** in green

##### Planned POS UI Screens

- [x] **`BoardingSheet` / `BoardingFormScreen`** — implemented as `boarding_sheet.dart`
- [x] **`ActivePassengerCard`** — implemented as `_PassengerSlotCard` in `dashboard_screen.dart`
- [x] **`ChangeCalculatorWidget`** — implemented inline in `_PassengerSlotCard`
- [x] **Queue Panel** — implemented in `BoardingSheet` tab 2 and `queue_manager_screen.dart`

### Phase 2f — UI Revamp (Navigation + Layout) ✅

> **Goal**: Reorient the app around the conductor's primary task — boarding passengers.
> The boarding form becomes the home screen; the dashboard is a swipe-right panel.

#### Navigation Architecture
- [x] Replace the single `DashboardScreen` root with `HomeShell` → `PageView` (2 pages, `initialPage: 0`)
  - **Page 0** (default home): `BoardingScreen` — full-screen boarding form (`lib/screens/boarding_screen.dart`)
  - **Page 1** (swipe right): `DashboardScreen` — occupancy panel and stats
- [x] Page dot indicator at the bottom — animated pill grows when active page (teal)
- [x] Swipe hint on Boarding page: `"Swipe for Dashboard"` label — auto-dismisses after first swipe
- [x] `PageControllerService` shared via `ChangeNotifierProvider` (`lib/services/page_controller_service.dart`) — `goToBoarding()` / `goToDashboard()` methods available app-wide

#### BoardingScreen (`lib/screens/boarding_screen.dart`) ✅
- [x] Promoted `_QuickTab` content into a full-screen `Scaffold`
- [x] Top header: TOMS logo, USB status pill, "Dashboard →" tap chip, overflow menu
- [x] Full-width boarding form — stop dropdowns with teal left-border when GPS auto-filled
- [x] Pending queue section inline below form (shows top 3 + count, "Manage →" link)
- [x] **[Queue Passenger]** button pinned at bottom with shadow shadow separator
- [x] Dashboard FAB removed — `BoardingSheet` modal no longer used from this path
- [x] `QueueManagerScreen` accessible via overflow menu

#### DashboardScreen (refactored) ✅
- [x] FAB removed
- [x] `← Boarding` chip added in app bar — taps `pageController.goToBoarding()`
- [x] `PageControllerService` imported and wired
- [x] All existing occupancy panel, stats row, slot cards, and transaction list preserved

#### Visual Design Tokens ✅
- [x] Boarding stop dropdown: teal left-border `BorderSide` when GPS auto-filled
- [x] Type chips: uniform `Expanded` height — all 4 chips identical size
- [x] Fare preview: large `₱XX.XX` (36px w800) center-aligned + discount breakdown below divider
- [x] `ClampingScrollPhysics` on `PageView` for crisp card-like swipe

### Phase 3 — GPS + Proximity Alarm ✅

#### 3a — Android Permissions
- [x] `ACCESS_FINE_LOCATION` + `ACCESS_COARSE_LOCATION` + `ACCESS_BACKGROUND_LOCATION`
- [x] `VIBRATE`
- [x] `POST_NOTIFICATIONS` + `RECEIVE_BOOT_COMPLETED` + `SCHEDULE_EXACT_ALARM`

#### 3b — GpsService (`lib/services/gps_service.dart`)
- [x] Continuous position stream via `Geolocator.getPositionStream` (20m distance filter, high accuracy)
- [x] Runtime permission request with descriptive error state if denied
- [x] `_updateNearestStop()` — iterates all stops, picks closest by Haversine distance
- [x] `distanceTo(stop)` helper — used by `ProximityService`
- [x] Exposed via `AppState`: `nearestStop`, `gpsTracking`, `gpsPermissionGranted`, `gpsError`

#### 3c — Boarding Stop Auto-fill (`boarding_screen.dart`) ✅
- [x] GPS pill button next to boarding stop accordion — accent-colored when tracking, grey when off
- [x] Tapping the GPS pill manually applies the current nearest stop (conductor must confirm — no auto-fill)
- [x] Sub-label shows `"GPS nearest: X (tap to use)"` or error/acquiring state
- [x] **GPS auto-fill removed** from `build()` — accordion stays open for conductor confirmation

#### 3d — ProximityService (`lib/services/proximity_service.dart`)
- [x] Listens to `GpsService` updates and scans all active sessions
- [x] Flags `session.alarmTriggered = true` when within 200m of destination
- [x] 1.5× hysteresis radius — clears alarm if bus moves away (missed stop recovery)
- [x] `onAlarmTriggered` callback — fires once per slot per trip (tracked via `_alreadyAlarmed` set)
- [x] `clearAlarm(uid)` — called by `AppState.markPaidManual()` to reset after payment

#### 3e — Alarm UX (`app_state.dart`)
- [x] `_onProximityAlarm(session)` — SOS vibration pattern `[400, 200, 400, 200, 800]ms`
- [x] `flutter_local_notifications` high-priority channel `toms_proximity_alarm`
- [x] Per-slot notification (slot number as notification ID) — title + fare + destination
- [x] `ProximityAlarmBanner` (built Phase 2c) surfaces in-app automatically on ALARMING state

### Phase 4 — Company Dashboard + Sync

#### 4a — Sync Infrastructure + Mobile Onboarding (Mobile Side)

##### Onboarding & Account
- [x] **`LoginScreen` / `OnboardingScreen`** — first launch requires internet to create/log in to a company account
  - Account creation links the device to a company + vehicle assignment
  - Auth token stored in `flutter_secure_storage` (not plain SharedPreferences)
  - App is locked behind login (`AuthWrapper` in `main.dart`); no boarding UI until account is confirmed
- [x] **`VehicleAssignmentScreen`** — conductor selects which bus they are operating at shift start
  - Dropdown of vehicles from `assets/vehicles.json` (API fetch deferred to 4d)
  - Sets `OccupancyService.vehicleId` and `maxCapacity` for the session
  - Can be changed between shifts via [End Shift] → returns to this screen

##### Sync & Shift Flow
- [x] `SyncService` finalization — `tokenGetter` callback injects live `AuthService` token; no hardcoded credentials
- [x] `share_plus` — conductor can share shift JSON at terminal (offline fallback) — `shift_summary_screen.dart` + `shift_history_screen.dart`
- [x] Retry queue drain confirmation — `_SyncStatusBar` widget in dashboard shows pending event count; clears when synced
- [x] **Shift end flow**: [End Shift] in ⋮ menu → confirm dialog → `AppState.endShift()` + `AuthService.assignVehicle('')` → returns to `VehicleAssignmentScreen`
- [x] **`ShiftHistoryScreen`** — browse and export logs from previous shifts (`lib/screens/shift_history_screen.dart`)
  - Lists past shifts from local SQLite grouped by calendar date
  - Per-day: passenger count, revenue, synced/pending badge
  - [Export JSON] / [Share] actions per shift via `share_plus`
  - Accessible from Dashboard ⋮ → Shift History

#### Phase 4 Web Architecture (APPROVED)

**1. Frontend (Company Dashboard)**
* **Framework**: **Vite + React (TypeScript)**. This provides a lightning-fast build environment for a Single Page Application (SPA), which is perfect for a dashboard with live-updating maps.
* **Design Philosophy**: **Ultra-Intuitive UI**. Since terminal employees and dispatchers may not be tech-literate, the UI will be large, clear, and focused on essential tasks without cluttered menus. We will use a custom glassmorphism design system with modern typography (e.g., Inter/Outfit) and dark mode.
* **Map Engine**: **MapLibre GL JS** (`react-map-gl` using `maplibre-gl`). MapLibre offers a high "wow" factor with highly customizable, sleek dark-mode base maps (like CartoDB Dark Matter) while being 100% free with no API keys required.

**2. Backend API**
* **Framework**: **Node.js + Express (TypeScript)**. Lightweight, highly compatible with WebSockets, and rapid to develop.
* **Database**: **PostgreSQL**. Ideal for structured relational data (Routes, Stops, Passenger Logs, Vehicles, and Companies).
* **Real-time**: **Socket.IO**. Essential for Phase 4c to stream live `OccupancySnapshot` data from the mobile app directly to the web dashboard in real-time.
* **Deployment**: **Docker & Docker Compose**. The entire backend (Node server + Postgres DB) will be containerized. This means it can be spun up with a single command (`docker-compose up`) on either a local company computer at the terminal or a remote Cloud VPS.

---

#### 4b — Route Builder (Company Dashboard)
> **New Feature**: The company admin defines official route stops directly on a map UI
> instead of manually editing `stops.json`. Stops are saved to the backend and pushed
> to conductors' phones on next sync.

**1. Backend Database Schema (PostgreSQL)**
We will create two tables to manage this data:
* `routes` table: `id` (PK), `name` (e.g., "Buru-un to City Proper"), `company_id`.
* `route_stops` table: `id` (PK), `route_id` (FK), `name`, `lat`, `lon`, `stop_order` (integer used for sequencing).

**2. Backend API Endpoints**
* `GET /api/routes/:id/stops`: Returns the ordered list of stops for the mobile app and dashboard.
* `POST /api/routes/:id/stops`: Accepts a JSON array of stops from the Web Dashboard and overwrites the existing stops for that route.

**3. Web Dashboard UI (`toms_web/src/pages/RouteBuilder.tsx`)**
* **Map View**: Integrated with `react-map-gl` and MapLibre. Clicking anywhere on the map drops a new draggable `Marker`.
* **Polyline**: A GeoJSON `Source` and `Layer` will draw a line connecting the markers in their sequential order.
* **Sidebar Panel**: A reorderable list of stops. Admin can rename stops or delete them. It includes a **[Save Route]** button that POSTs to the backend.

**4. Mobile Sync (Flutter)**
* `SyncService` (or a new `RouteService`) will fetch `GET /api/routes/:id/stops` upon successful login.
* The fetched stops will be cached in SQLite or `path_provider` local JSON.
* `AppState.stops` will load from this cache instead of the bundled `assets/stops.json`, allowing the company to remotely update routes!

**Remaining Phase 4b Checklist Items:**
- [x] **Backend DB Schema** — `routes` and `route_stops` tables created in `initDb()` in `index.ts`.
- [x] **`GET /api/routes/:id/stops`** — Implemented, returns ordered stop list for mobile and dashboard.
- [x] **`POST /api/routes/:id/stops`** — Implemented, replaces all stops for a route.
- [x] **`RouteBuilder.tsx`** — MapLibre map with click-to-drop `Marker`, GeoJSON polyline `Source`/`Layer`, sortable sidebar via `dnd-kit`, and Save button.
- [x] **Mobile Sync** — `app_state.dart` fetches `/api/routes/1/stops` on boot, caches to `SharedPreferences`, falls back to `assets/stops.json`.

#### 4b.1 — Route Builder Enhancements (Proposed)
> **Open Question**: You requested adding Route Builder enhancements to the plan. I have proposed three powerful features below. Please let me know which of these you would like to prioritize or if you had something else in mind!

- [x] **Road-Snapped Routing**: Currently, the polyline draws a straight line between stops. We can integrate the free OSRM (Open Source Routing Machine) API to automatically snap the blue route line to actual city streets.
- [x] **Custom Geo-fence Radius**: Allow the admin to visually adjust a circle around each stop on the map (e.g., 50m vs 100m) to customize exactly when the conductor's proximity alarm triggers.
- [x] **Fare Matrix Editor**: A panel that allows the admin to set the Base Fare (₱) and Per-KM Fare directly on the route, which syncs to the mobile app instead of hardcoding `17.00` and `2.30` in the Dart code.

#### 4c — Company Dashboard UI (Live Fleet Tracking)
> **New Feature**: The dashboard provides a real-time overview of the entire fleet.
> As conductors sync their data (boarding/alighting), the dashboard updates live
> using WebSockets, showing occupancy, revenue, and location.

**1. Backend Real-time Engine (`toms_backend`)**
* Create an `events` table in SQLite to store all transaction payloads from the mobile app.
* Add a `POST /api/events` endpoint. The mobile `SyncService` will push all offline and online events here.
* Upon receiving a new event, the backend saves it and instantly broadcasts a `fleet_update` event via **Socket.IO** to all connected web clients.

**2. Web Dashboard UI (`toms_web/src/pages/DashboardHome.tsx`)**
* **Fleet Overview Grid**: A responsive grid of "Bus Cards". Each card displays:
  - Vehicle ID & Assigned Route
  - Live Occupancy Progress Bar (e.g., 24/30 seats full)
  - Daily Revenue (calculated from synced events)
* **Live Socket Connection**: Connects to the backend via `socket.io-client` to listen for `fleet_update` events and instantly animate the UI changes without reloading the page.
* **Seat Map Modal**: Clicking a Bus Card opens a glassmorphism modal showing the exact seat layout and which specific seats are currently occupied, perfectly mirroring the conductor's phone.

**3. Mobile Sync Integration (`toms_mobile`)**
* Update `SyncService.dart` to point to `http://10.0.2.2:3000/api/events` instead of the placeholder URL.
* Ensure the sync payload includes the exact array of occupied seats so the dashboard can render the seat map perfectly.

**Phase 4c Checklist:**
- [x] **`events` table** — Created in SQLite `initDb()` with full schema.
- [x] **`POST /api/events`** — Accepts batched event arrays from mobile `SyncService`.
- [x] **Socket.IO `fleet_update`** — Emitted after every successful `POST /api/events` COMMIT, including real-time daily revenue.
- [x] **`SyncService.dart` URL** — Updated to `http://10.0.2.2:3000/api/events`.
- [x] **Seat map in sync payload** — `app_state.dart` serializes `getPassengerSlots()` as JSON and passes `seatMap` parameter.
- [x] **`DashboardHome.tsx` Bus Cards** — Fleet grid with live occupancy progress bar and daily revenue per bus.
- [x] **Socket.IO client** — `socket.on('fleet_update', ...)` listener with live UI state update.
- [x] **Seat Map Modal** — Glassmorphism modal with per-slot color coding (Empty / Unpaid / Paid / ALARM).

#### 4d — Historical Analytics & Audit Logs (Company Dashboard)
> **New Feature**: While Phase 4c provided a live view of the fleet, Phase 4d builds the historical reporting suite. Admins can view past transactions, dispute fares, and analyze daily/weekly revenue trends.

**1. Backend Analytics API (`toms_backend`)**
- [x] `GET /api/analytics/revenue` — Aggregates `events` table by date, passenger type, and calculates total sales/trips.
- [x] `GET /api/audit/logs` — Paginated and searchable transaction logs with full metadata filters.
- [x] `GET /api/conductors` — Dynamically queries SQLite to compile active conductor shifts, contact details, and today's sales sums.

**2. Web Dashboard UI (`toms_web/src/pages`)**
- [x] **Analytics Page (`/analytics`)** — Premium visual charts showing revenue trend, passenger demographics, and operational insights.
- [x] **Audit Logs Page (`/audit`)** — Searchable data table with date-range filters, custom event tags, pagination, and details modal.
- [x] **Conductors Directory Page (`/conductors`)** — Dynamic staff tracking table displaying on-shift/offline statuses, dynamic collections, and linkages to corresponding bus logs.

> [!IMPORTANT]
> **User Review Required**: Do you approve this execution plan for Phase 4d (Transaction Audit Logs & Revenue Analytics)? Are there any specific charts or metrics you want prioritized?

### Phase 5 — Hardware Config & Slave Alarm (Firmware, Optional)
- [ ] `TOMS_MSG_ALARM_CMD` in `protocol.h`
- [ ] Slave: alarm cmd → red screen + "Please Pay" UI
- [ ] Master: `send_alarm` USB cmd → ESP-NOW to target slave
- [ ] Flutter `ProximityService` triggers slave alarm alongside phone alarm
- [ ] **Fare dictionary push to Master** — phone sends updated fare table to Master via USB `config` command
  - Triggered from vehicle assignment or a [Sync Config] action in the overflow menu
  - Master stores the fare dict in NVS (used by Slave on next board command via `fare_id` lookup)
  - Matches §3.5.1 step 6: "fare dictionary loading from NVS via `toms_fare_dict_load`"

---
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

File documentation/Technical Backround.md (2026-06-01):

# Technical Background

This chapter presents the technical background underlying the Transportation Occupancy Monitoring System (TOMS). It discusses the technologies, standards, and architectural concepts employed in the system — explaining what each technology is, why it is relevant to the problem domain, and how it supports the proposed solution.

---

## 3.1 Overview of Automated Fare Collection Systems

Automated Fare Collection (AFC) systems replace manual ticketing and cash handling in public transportation with electronic mechanisms for passenger identification, fare computation, and revenue recording. Early AFC deployments used magnetic-stripe tickets and token dispensers in metro rail networks; contemporary systems integrate contactless smart cards, mobile payments, and real-time cloud dashboards (Suvarna et al., 2022; Kulange et al., 2025).

AFC systems are relevant to TOMS because the Iligan City minibus sector still relies on the traditional "konduktor" model — a human conductor who manually counts passengers, calculates fares, and collects cash — a method that is demonstrably susceptible to human error, revenue leakage, and the absence of verifiable transaction records (Kannan et al., 2020; Ingabire, 2023). Research indicates that transitioning to automated systems can reduce transit operating costs by up to 30% and eliminate the "Human Error Fallacy" inherent in manual manifest generation (Adebiyi et al., 2021; Lam et al., 2026).

In the TOMS architecture, automation is achieved through a handheld Point-of-Sale (POS) terminal that records every boarding event as a structured digital record, calculates the distance-based fare from GPS coordinates, issues a QR-coded receipt on a passenger-held Slave terminal, and uploads all transactions to a cloud dashboard when connectivity is available.

---
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

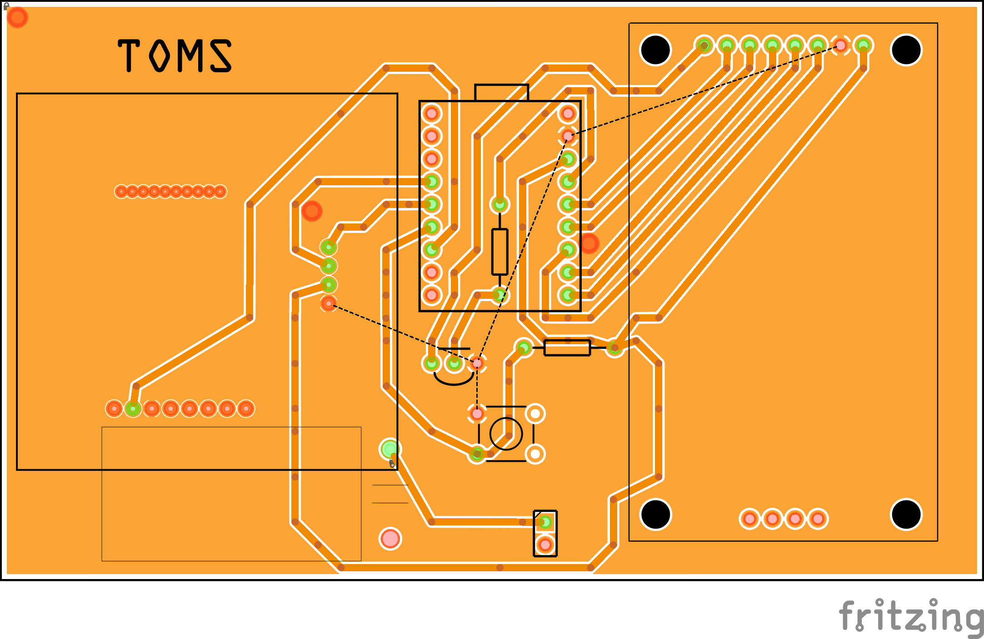
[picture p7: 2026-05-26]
hardware/slave/pcb/Slave Design BJT v2.1_pcb.png

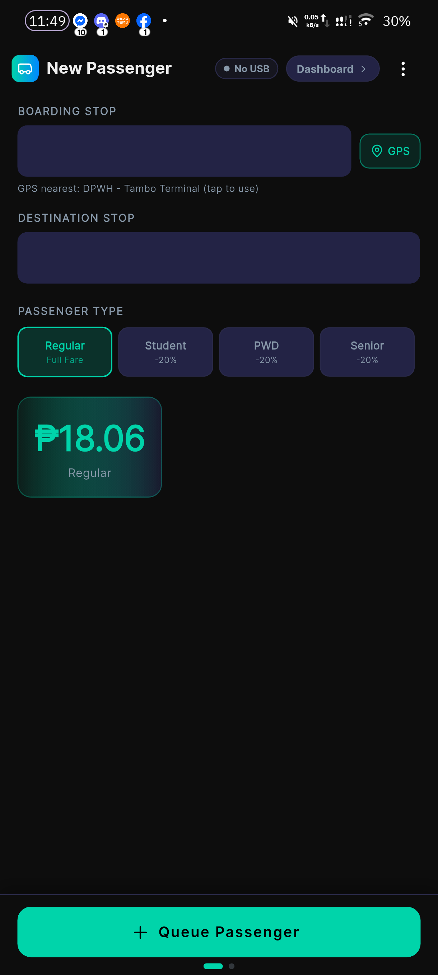
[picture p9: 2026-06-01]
toms_mobile/screen2.png

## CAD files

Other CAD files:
TOMS 1.2.skp

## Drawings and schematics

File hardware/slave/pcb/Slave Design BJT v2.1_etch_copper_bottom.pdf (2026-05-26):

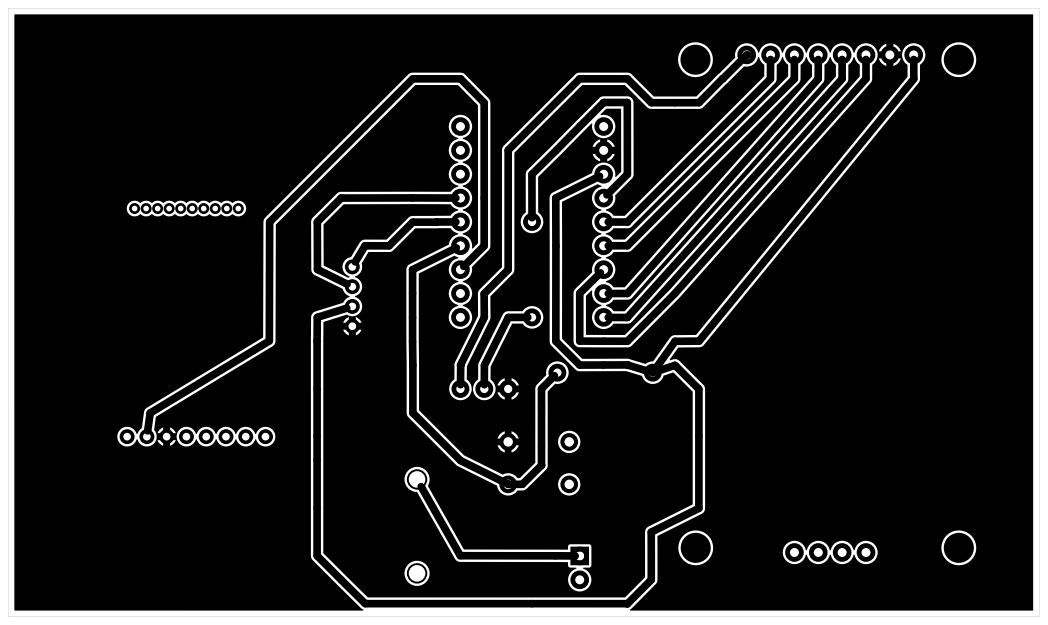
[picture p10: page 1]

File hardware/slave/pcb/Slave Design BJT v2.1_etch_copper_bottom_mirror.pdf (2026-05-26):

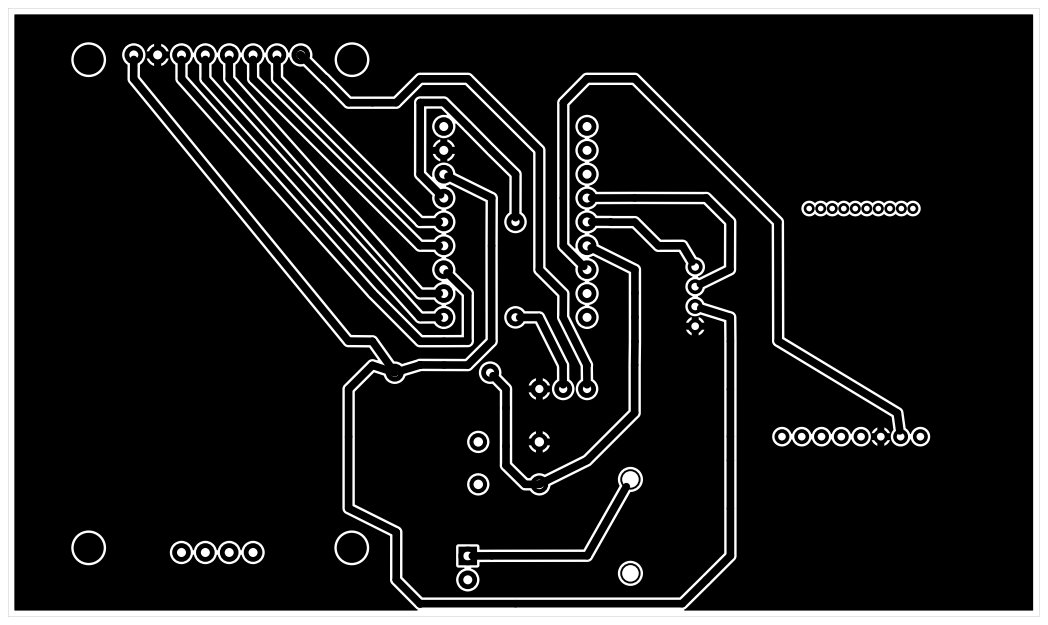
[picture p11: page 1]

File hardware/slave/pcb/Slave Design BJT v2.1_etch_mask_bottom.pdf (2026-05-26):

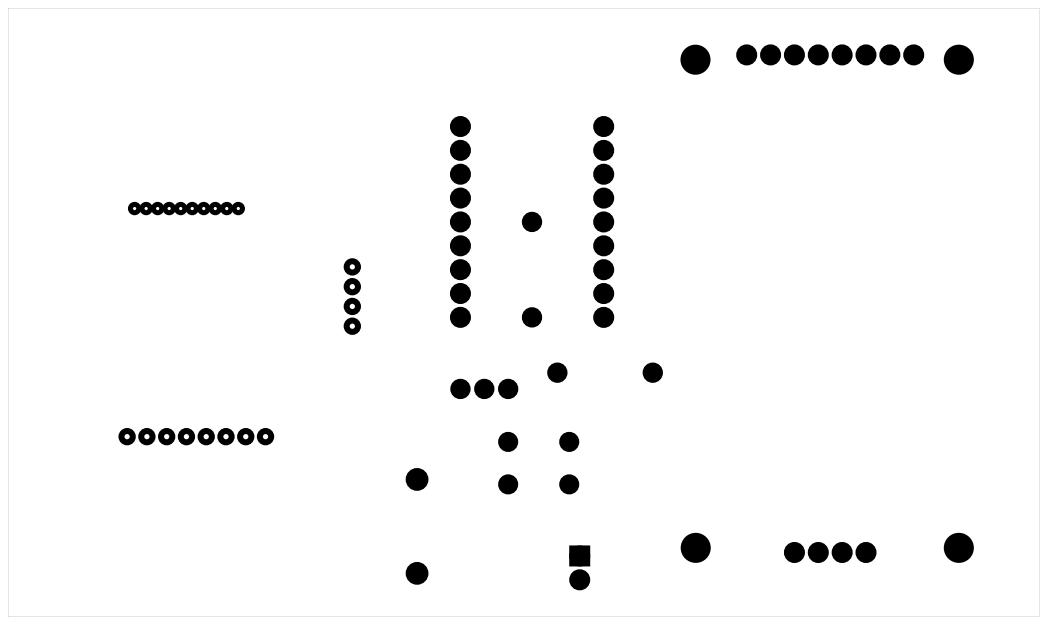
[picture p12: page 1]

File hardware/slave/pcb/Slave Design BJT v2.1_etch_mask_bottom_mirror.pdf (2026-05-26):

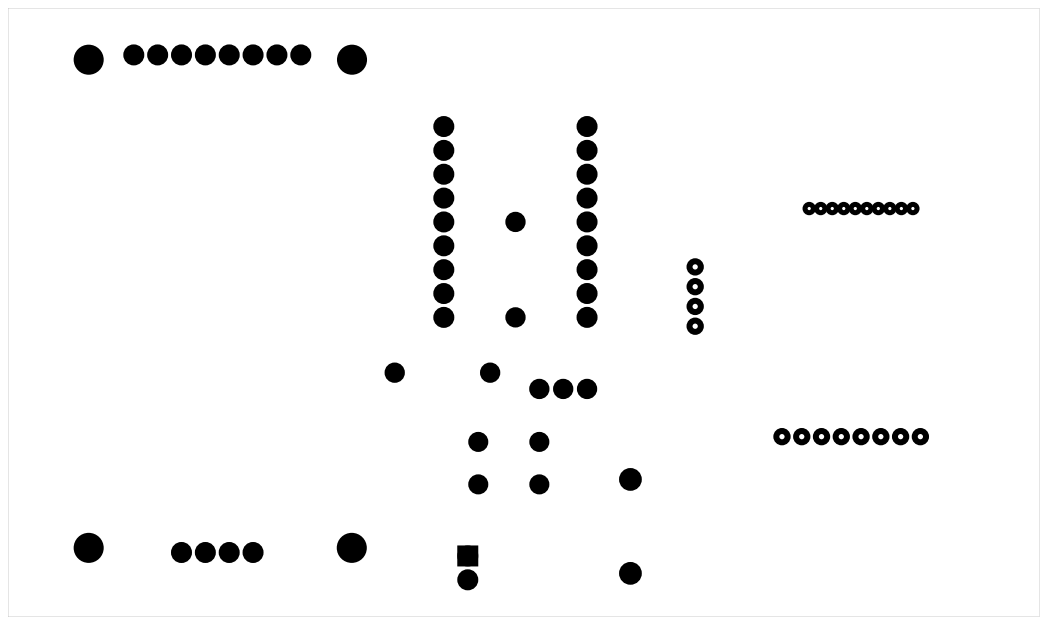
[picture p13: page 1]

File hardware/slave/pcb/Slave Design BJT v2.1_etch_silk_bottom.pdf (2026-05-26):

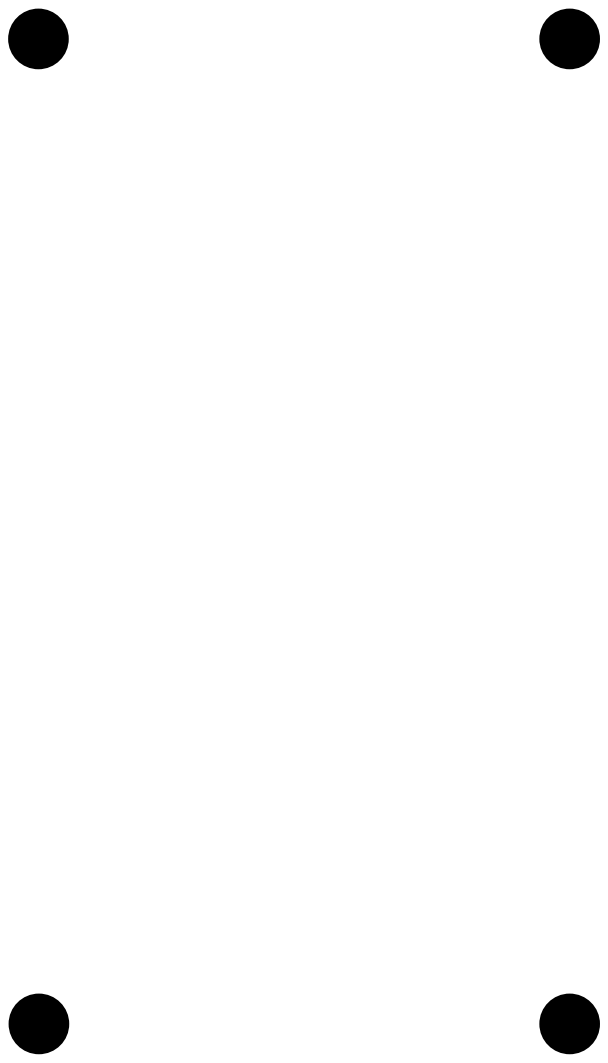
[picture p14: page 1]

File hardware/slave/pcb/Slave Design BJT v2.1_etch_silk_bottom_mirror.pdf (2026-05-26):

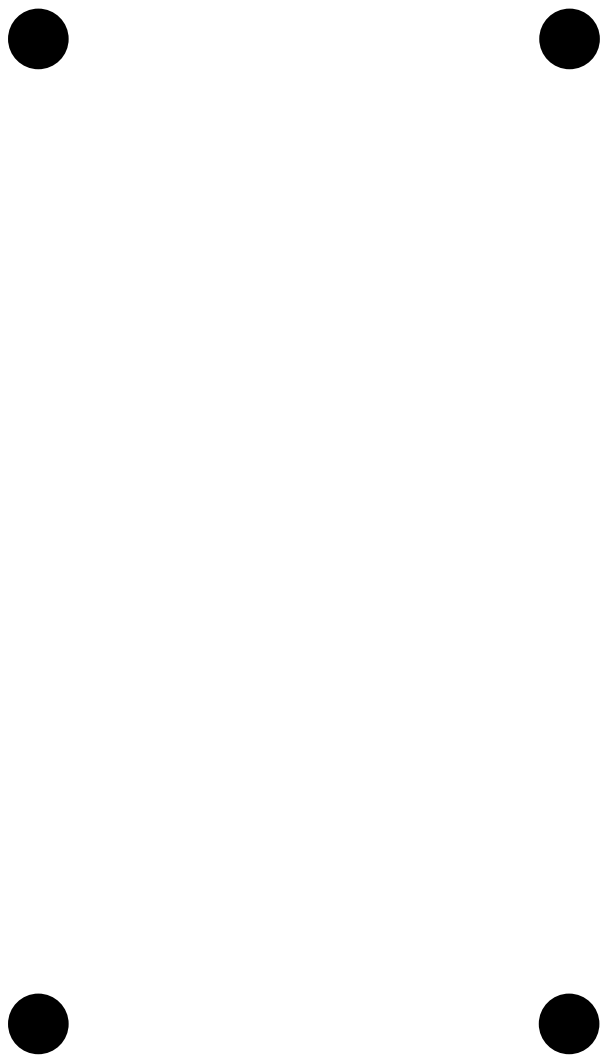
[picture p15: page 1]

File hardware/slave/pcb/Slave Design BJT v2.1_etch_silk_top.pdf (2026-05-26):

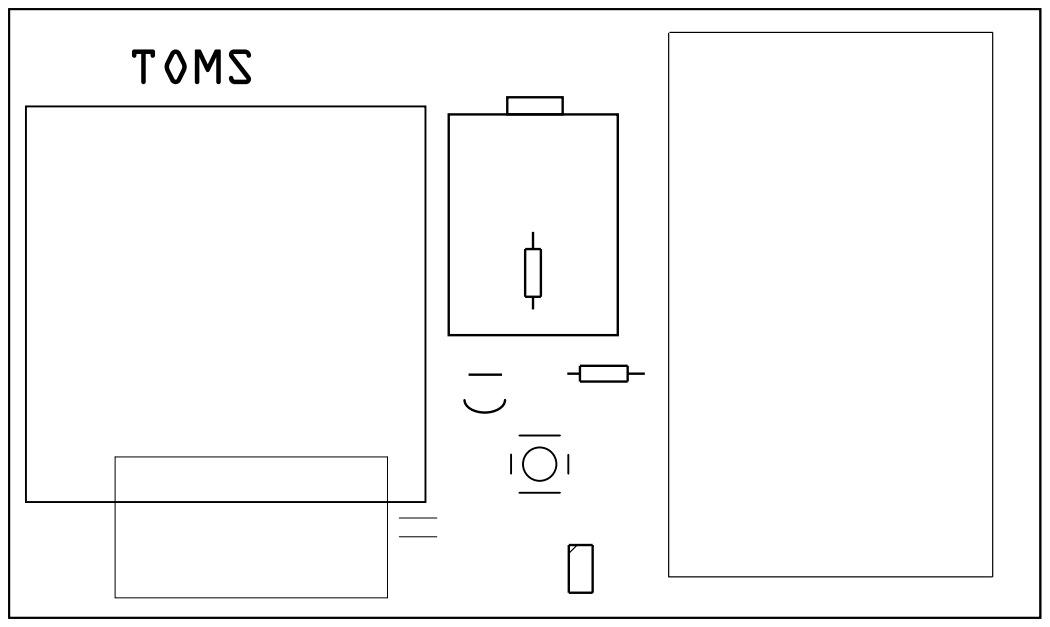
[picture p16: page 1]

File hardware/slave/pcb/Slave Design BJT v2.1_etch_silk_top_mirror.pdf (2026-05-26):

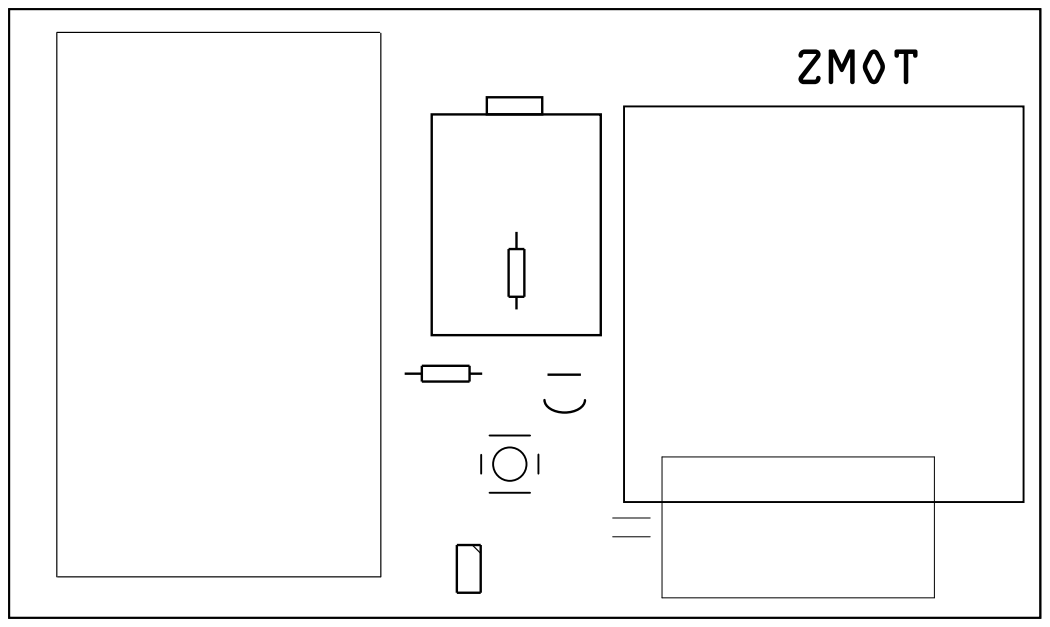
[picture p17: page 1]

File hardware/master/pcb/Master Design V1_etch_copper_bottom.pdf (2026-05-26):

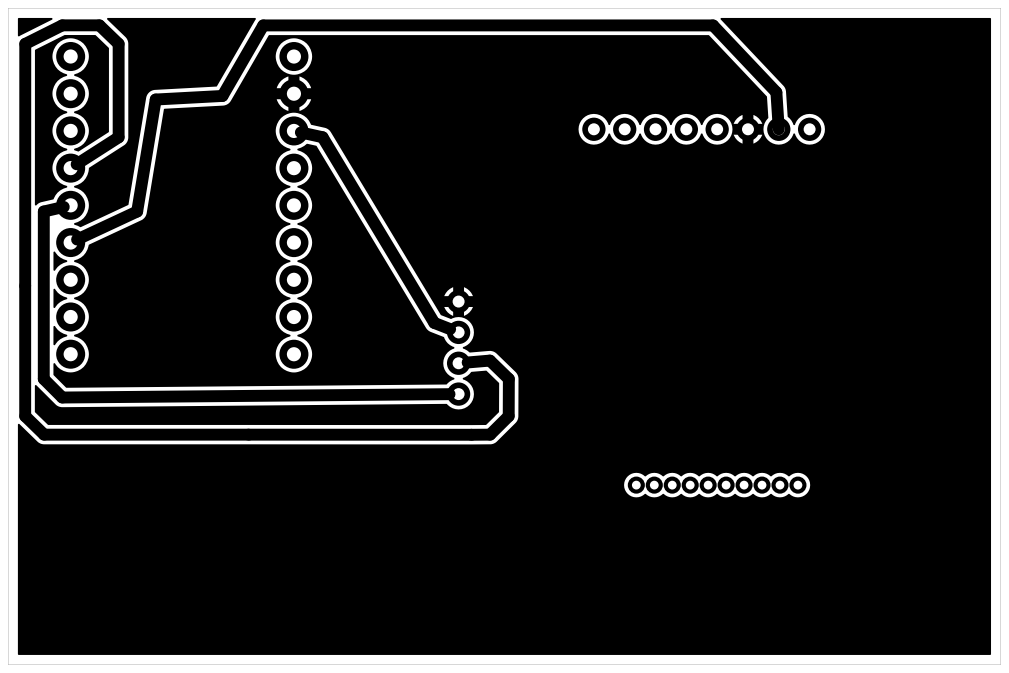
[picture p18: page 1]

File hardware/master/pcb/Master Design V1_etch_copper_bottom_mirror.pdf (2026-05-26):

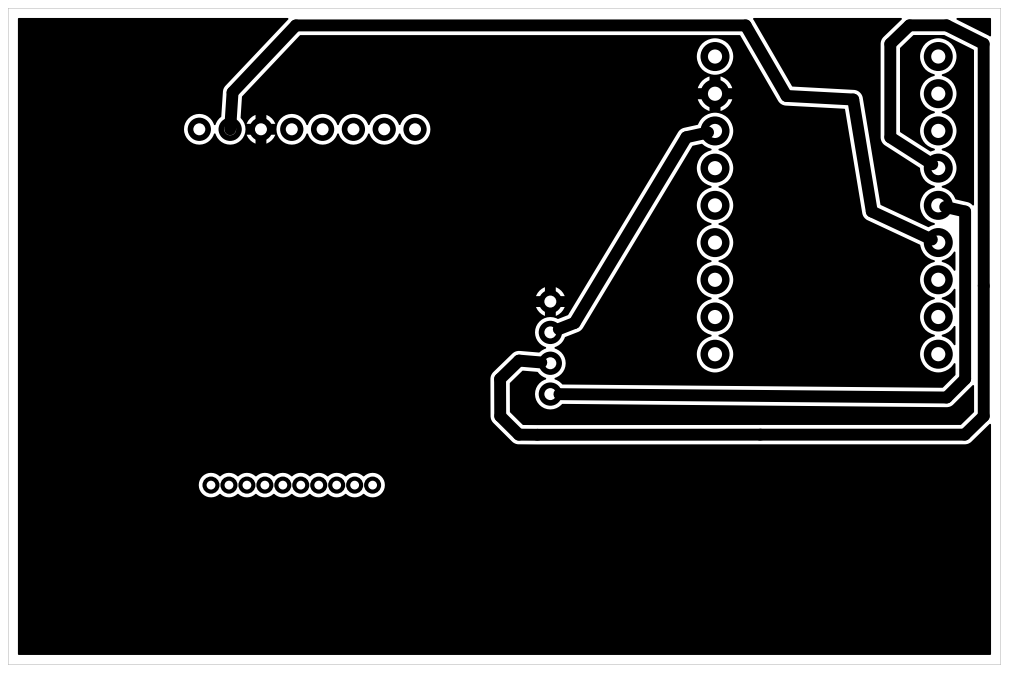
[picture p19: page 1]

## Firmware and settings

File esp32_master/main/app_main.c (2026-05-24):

/**
 * @file app_main.c
 * @brief TOMS Master — Main entry point and FreeRTOS task orchestrator.
 *
 * Initializes all subsystems (NVS, SPIFFS, Wi-Fi/ESP-NOW, USB CDC, NFC,
 * battery monitoring) and launches dedicated FreeRTOS tasks on the
 * ESP32-S3's dual cores.
 *
 * Task assignment:
 *   Core 0: USB CDC (phone I/O), NFC sync (PN532 P2P), storage flush
 *   Core 1: ESP-NOW (radio, latency-sensitive)
 */

#include <string.h>
#include <stdio.h>
#include "freertos/FreeRTOS.h"
#include "freertos/task.h"
#include "esp_log.h"
#include "esp_system.h"
#include "esp_mac.h"
#include "esp_timer.h"

/* TOMS modules */
#include "storage.h"
#include "crypto.h"
#include "espnow_comm.h"
#include "usb_cdc.h"
#include "nfc_sync.h"
#include "power.h"
#include "protocol.h"
#include "fare_dict.h"

static const char *TAG = "toms_master";

/* ── Configuration ────────────────────────────────────────────────────── */

/* Slave MAC — updated when a Slave authenticates via UART UID handshake */
static uint8_t s_slave_mac[6] = {0xFF, 0xFF, 0xFF, 0xFF, 0xFF, 0xFF};

/* ESP-NOW LMK for native encryption (16 bytes) */
static const uint8_t s_espnow_lmk[16] = {
    0x54, 0x4F, 0x4D, 0x53, 0x5F, 0x4C, 0x4D, 0x4B,
    0x5F, 0x53, 0x4C, 0x41, 0x56, 0x45, 0x30, 0x31
};

/* Sequence counters */
static uint8_t s_espnow_seq = 0;

/* Default vehicle ID — updated via USB from phone */
static uint8_t s_vehicle_id[16] = "VEH001";

/* Active fare/route config (updated from phone via USB sync) */
static uint16_t s_fare_centavos  = 1300;  /* Default: P13.00 */
static uint8_t  s_route_id       = 1;

/* Fare dictionary (shared with Slaves, synced via ESP-NOW CONFIG_SYNC) */
static toms_fare_dict_t s_fare_dict;

/* ── Forward Declarations ─────────────────────────────────────────────── */

static void on_usb_message(const char *data, size_t len);
static void on_nfc_tap(const uint8_t *slave_uid, uint8_t uid_len);
static void on_nfc_connect(bool connected);
static void espnow_handler_task(void *arg);
static void storage_flush_task(void *arg);
static void forward_passenger_to_phone(const toms_passenger_event_t *event);
static void dispatch_board_command_espnow(const uint8_t *slave_mac);

/* ── USB Message Handler ──────────────────────────────────────────────── */

/**
 * Handle JSON-line messages from the phone.
 *
 * Expected format:
 *   {"cmd":"handshake","version":"1.0"}
 *   {"cmd":"sync_fare_table","data":{...}}
 *   {"cmd":"get_status"}
 *   {"cmd":"set_slave_mac","mac":"AA:BB:CC:DD:EE:FF"}
 */
static void on_usb_message(const char *data, size_t len)
{
    ESP_LOGI(TAG, "USB RX: %.*s", (int)len, data);

    /* Simple command parsing (production should use cJSON) */
    if (strstr(data, "\"handshake\"")) {
        /* Respond with device info */
        uint8_t mac[6];
        toms_espnow_get_mac(mac);

        char resp[256];
        snprintf(resp, sizeof(resp),
                 "{\"evt\":\"ack\",\"device\":\"toms_master\","
                 "\"mac\":\"%02X:%02X:%02X:%02X:%02X:%02X\","
                 "\"battery_pct\":%d,"
                 "\"pending_logs\":%d}",
                 mac[0], mac[1], mac[2], mac[3], mac[4], mac[5],
                 toms_power_get_battery_pct(),
                 toms_storage_get_pending_count());
        toms_usb_cdc_send(resp);

    } else if (strstr(data, "\"get_status\"")) {
        uint32_t batt_mv = toms_power_get_battery_mv();
        uint8_t  batt_pct = toms_power_get_battery_pct();
        size_t total = 0, used = 0;
        toms_storage_get_stats(&total, &used);

        char resp[256];
        snprintf(resp, sizeof(resp),
                 "{\"evt\":\"status\",\"battery_mv\":%lu,\"battery_pct\":%d,"
                 "\"storage_total\":%u,\"storage_used\":%u,"
                 "\"pending_logs\":%d,"
                 "\"nfc_state\":%d}",
                 (unsigned long)batt_mv, batt_pct,
                 (unsigned)total, (unsigned)used,
                 toms_storage_get_pending_count(),
                 (int)toms_nfc_sync_get_state());
        toms_usb_cdc_send(resp);

    } else if (strstr(data, "\"sync_fare_table\"")) {
        /* Forward fare table to slave via ESP-NOW */
        /* TODO: Parse fare data and build config payload */
        ESP_LOGI(TAG, "Fare table sync requested (not yet implemented)");
        toms_usb_cdc_send("{\"evt\":\"ack\",\"cmd\":\"sync_fare_table\"}");

    } else {
        ESP_LOGW(TAG, "Unknown USB command");
        toms_usb_cdc_send("{\"evt\":\"error\",\"msg\":\"unknown command\"}");
    }
}

/* ── NFC Handlers ─────────────────────────────────────────────────────── */

/**
 * Called immediately when a Slave is detected via NFC tap (Phase 1: optimistic).
 * The slave_uid is the eFuse MAC extracted from the Slave's NFCID3.
 * The BOARD_CMD is sent over NFC by nfc_sync.c automatically.
 * PASSENGER_BOARD confirmation arrives later via ESP-NOW (Phase 2).
 */
static void on_nfc_tap(const uint8_t *slave_uid, uint8_t uid_len)
{
    ESP_LOGI(TAG, "NFC tap: Slave UID=%02X:%02X:%02X:%02X:%02X:%02X",
             slave_uid[0], slave_uid[1], slave_uid[2],
             slave_uid[3], slave_uid[4], slave_uid[5]);

    /* Update known Slave MAC for ESP-NOW confirmation path */
    memcpy(s_slave_mac, slave_uid, 6);
    toms_espnow_add_peer(s_slave_mac, NULL, TOMS_ESPNOW_CHANNEL);

    /* Phase 1: Optimistic count — notify phone immediately */
    char msg[192];
    snprintf(msg, sizeof(msg),
             "{\"evt\":\"nfc_tap\","
             "\"uid\":\"%02X%02X%02X%02X%02X%02X\","
             "\"status\":\"pending\"}",
             slave_uid[0], slave_uid[1], slave_uid[2],
             slave_uid[3], slave_uid[4], slave_uid[5]);
    toms_usb_cdc_send(msg);
}

static void on_nfc_connect(bool connected)
{
    ESP_LOGI(TAG, "NFC: %s", connected ? "CONNECTED" : "DISCONNECTED");
    char msg[64];
    snprintf(msg, sizeof(msg), "{\"evt\":\"nfc\",\"state\":\"%s\"}",
             connected ? "connected" : "disconnected");
    toms_usb_cdc_send(msg);
}

/* ── ESP-NOW Handler Task ─────────────────────────────────────────────── */

static void espnow_handler_task(void *arg)
{
    (void)arg;
    ESP_LOGI(TAG, "ESP-NOW handler task started on core %d", xPortGetCoreID());

    toms_espnow_event_t event;

    while (1) {
        if (toms_espnow_receive(&event, 1000)) {
            ESP_LOGI(TAG, "ESP-NOW RX from " MACSTR ": type=0x%02X",
                     MAC2STR(event.src_mac), event.packet.msg_type);

            /* Register the sender as a peer dynamically so we can send ACKs/commands back. 
             * Passing NULL for LMK disables native CCMP encryption for this unicast link,
             * which is necessary since the Slave hasn't explicitly registered our MAC yet.
             * (Payload is still AES-256 encrypted by toms_crypto_encrypt). */
            toms_espnow_add_peer(event.src_mac, NULL, TOMS_ESPNOW_CHANNEL);

            switch (event.packet.msg_type) {
            case TOMS_MSG_PASSENGER_BOARD: {
                if (event.packet.length >= sizeof(toms_passenger_event_t)) {
                    const toms_passenger_event_t *pe =
                        (const toms_passenger_event_t *)event.packet.payload;

                    /* Log to SPIFFS */
                    toms_storage_log_event(pe);

                    /* Forward to phone */
                    forward_passenger_to_phone(pe);

                    /* Send ACK to slave */
                    toms_packet_t ack;
                    toms_packet_build(&ack, TOMS_MSG_ACK_MASTER, s_espnow_seq++, NULL, 0);
                    toms_espnow_send(event.src_mac, &ack);
                }
                break;
            }

            case TOMS_MSG_BUTTON_PRESS:
                ESP_LOGI(TAG, "Button press from slave " MACSTR, MAC2STR(event.src_mac));

                /* Notify phone */
                {
                    char msg[128];
                    snprintf(msg, sizeof(msg),
                             "{\"evt\":\"button_press\",\"source\":\"slave\","
                             "\"mac\":\"%02X:%02X:%02X:%02X:%02X:%02X\"}",
                             event.src_mac[0], event.src_mac[1], event.src_mac[2],
                             event.src_mac[3], event.src_mac[4], event.src_mac[5]);
                    toms_usb_cdc_send(msg);
                }

                /* ACK the button press */
                {
                    toms_packet_t ack;
                    toms_packet_build(&ack, TOMS_MSG_ACK_MASTER, s_espnow_seq++, NULL, 0);
                    toms_espnow_send(event.src_mac, &ack);
                }

                /* Dispatch BOARD_COMMAND back to the Slave via ESP-NOW */
                dispatch_board_command_espnow(event.src_mac);
                break;

            case TOMS_MSG_HEARTBEAT:
                ESP_LOGD(TAG, "Heartbeat from slave");
                break;

            default:
                ESP_LOGD(TAG, "Unhandled ESP-NOW type: 0x%02X", event.packet.msg_type);
                break;
            }
        }
    }
}

/* ── ESP-NOW Board Command Dispatch ──────────────────────────────────── */

/**
 * Send a BOARD_COMMAND via ESP-NOW to a Slave that pressed its button.
 * The target_uid in the payload is extracted from the Slave's button-press
 * packet (which includes the first 6 bytes of the UID).
 */
static void dispatch_board_command_espnow(const uint8_t *slave_mac)
{
    toms_board_command_t cmd = {0};

    /* Use the Slave's MAC as the target_uid (first 6 bytes) */
    memcpy(cmd.target_uid, slave_mac, 6);
    cmd.timestamp     = (uint32_t)(esp_timer_get_time() / 1000000ULL);
    cmd.fare_centavos = s_fare_centavos;
    cmd.seat_number   = 0;   /* Unknown seat for button-press flow */
    cmd.route_id      = s_route_id;
    memcpy(cmd.vehicle_id, s_vehicle_id, 16);

    toms_packet_t pkt;
    toms_packet_build(&pkt, TOMS_MSG_BOARD_COMMAND, s_espnow_seq++,
                      (const uint8_t *)&cmd, sizeof(cmd));

    if (toms_espnow_send(slave_mac, &pkt)) {
        ESP_LOGI(TAG, "BOARD_COMMAND sent via ESP-NOW to " MACSTR,
                 MAC2STR(slave_mac));
    } else {
        ESP_LOGE(TAG, "Failed to send BOARD_COMMAND via ESP-NOW");
    }
}

/* ── Storage Flush Task ───────────────────────────────────────────────── */

static void storage_flush_task(void *arg)
{
    (void)arg;
    ESP_LOGI(TAG, "Storage flush task started");

    while (1) {
        vTaskDelay(pdMS_TO_TICKS(60000)); /* Every 60 seconds */
        toms_storage_cleanup();

        /* Log stats */
        size_t total = 0, used = 0;
        toms_storage_get_stats(&total, &used);
        ESP_LOGI(TAG, "Storage: %u/%u bytes (%d pending logs)",
                 (unsigned)used, (unsigned)total,
                 toms_storage_get_pending_count());
    }
}

/* ── Utility ──────────────────────────────────────────────────────────── */

static void forward_passenger_to_phone(const toms_passenger_event_t *event)
{
    if (!toms_usb_cdc_is_connected()) {
        ESP_LOGD(TAG, "USB not connected, skipping phone forward");
        return;
    }

    char json[384];
    snprintf(json, sizeof(json),
             "{\"evt\":\"passenger\","
             "\"timestamp\":%lu,"
             "\"boarding_type\":%d,"
             "\"fare_centavos\":%d,"
             "\"seat\":%d,"
             "\"route\":%d,"
             "\"passenger_id\":\"%02X%02X%02X%02X%02X%02X%02X%02X"
             "%02X%02X%02X%02X%02X%02X%02X%02X\"}",
             (unsigned long)event->timestamp,
             event->boarding_type,
             event->fare_centavos,
             event->seat_number,
             event->route_id,
             event->passenger_id[0],  event->passenger_id[1],
             event->passenger_id[2],  event->passenger_id[3],
             event->passenger_id[4],  event->passenger_id[5],
             event->passenger_id[6],  event->passenger_id[7],
             event->passenger_id[8],  event->passenger_id[9],
             event->passenger_id[10], event->passenger_id[11],
             event->passenger_id[12], event->passenger_id[13],
             event->passenger_id[14], event->passenger_id[15]);

    toms_usb_cdc_send(json);
}

/* ── Main Entry Point ─────────────────────────────────────────────────── */

void app_main(void)
{
    ESP_LOGI(TAG, "=== TOMS Master Firmware ===");
    ESP_LOGI(TAG, "Firmware version: 0.1.0");
    ESP_LOGI(TAG, "Free heap: %lu bytes", (unsigned long)esp_get_free_heap_size());

    /* ── Step 1: Storage (NVS + SPIFFS) ─────────────────────────────── */
    ESP_LOGI(TAG, "[1/7] Initializing storage...");
    int err = toms_storage_init();
    if (err != 0) {
        ESP_LOGE(TAG, "Storage init failed (%d) — halting", err);
        return;
    }

    /* ── Step 2: Crypto (AES-256 key from NVS) ──────────────────────── */
    ESP_LOGI(TAG, "[2/7] Initializing crypto...");
    err = toms_crypto_init();
    if (err != 0) {
        ESP_LOGE(TAG, "Crypto init failed (%d) — halting", err);
        return;
    }

    /* ── Step 3: ESP-NOW ────────────────────────────────────────────── */
    ESP_LOGI(TAG, "[3/7] Initializing ESP-NOW...");
    err = toms_espnow_init(NULL);  /* Use default PMK */
    if (err != 0) {
        ESP_LOGE(TAG, "ESP-NOW init failed (%d) — halting", err);
        return;
    }

    /* Add slave peer (broadcast by default until configured) */
    toms_espnow_add_peer(s_slave_mac, s_espnow_lmk, TOMS_ESPNOW_CHANNEL);

    /* ── Step 4: USB CDC ────────────────────────────────────────────── */
    ESP_LOGI(TAG, "[4/7] Initializing USB CDC...");
    err = toms_usb_cdc_init();
    if (err != 0) {
        ESP_LOGE(TAG, "USB CDC init failed (%d) — continuing without USB", err);
    }
    toms_usb_cdc_set_recv_cb(on_usb_message);

    /* ── Step 5: NFC Sync (PN532 Initiator) ──────────────────────────── */
    ESP_LOGI(TAG, "[5/8] Initializing NFC sync...");
    err = toms_nfc_sync_init();
    if (err != 0) {
        ESP_LOGE(TAG, "NFC sync init failed (%d) — continuing", err);
    }
    toms_nfc_sync_set_tap_cb(on_nfc_tap);
    toms_nfc_sync_set_connect_cb(on_nfc_connect);

    /* ── Step 6: Fare Dictionary ───────────────────────────────────── */
    ESP_LOGI(TAG, "[6/8] Loading fare dictionary...");
    toms_fare_dict_load(&s_fare_dict);
    ESP_LOGI(TAG, "Fare dictionary: %d entries loaded", s_fare_dict.count);

    /* Set active fare for NFC tap */
    toms_nfc_sync_set_fare(1, 0);  /* Default: fare_id=1, seat=0 */

    /* ── Step 7: Power monitoring ───────────────────────────────────── */
    ESP_LOGI(TAG, "[7/8] Initializing power monitoring...");
    toms_power_init();
    ESP_LOGI(TAG, "Battery: %lu mV (%d%%)",
             (unsigned long)toms_power_get_battery_mv(),
             toms_power_get_battery_pct());

    /* ── Step 8: Launch FreeRTOS tasks ──────────────────────────────── */
    ESP_LOGI(TAG, "[8/8] Launching tasks...");

    /* USB CDC task — Core 0, priority 5 */
    xTaskCreatePinnedToCore(toms_usb_cdc_task, "usb_cdc",
                            4096, NULL, 5, NULL, 0);

    /* ESP-NOW handler — Core 1, priority 6 (latency-sensitive) */
    xTaskCreatePinnedToCore(espnow_handler_task, "espnow_handler",
                            4096, NULL, 6, NULL, 1);

    /* NFC sync (Initiator) — Core 0, priority 4 */
    xTaskCreatePinnedToCore(toms_nfc_sync_task, "nfc_sync",
                            4096, NULL, 4, NULL, 0);

    /* Storage flush — Core 0, priority 3 */
    xTaskCreatePinnedToCore(storage_flush_task, "storage_flush",
                            2048, NULL, 3, NULL, 0);

    ESP_LOGI(TAG, "=== TOMS Master ready ===");
    ESP_LOGI(TAG, "Free heap after init: %lu bytes",
             (unsigned long)esp_get_free_heap_size());
}

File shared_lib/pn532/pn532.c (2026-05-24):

/**
 * @file pn532.c
 * @brief PN532 NFC controller I2C driver implementation.
 *
 * Handles frame encoding/decoding, ACK verification, IRQ-based ready
 * detection, and all NFC-DEP Initiator/Target commands.
 */

#include "pn532.h"

#include <string.h>
#include "esp_log.h"
#include "driver/i2c.h"
#include "driver/gpio.h"
#include "freertos/FreeRTOS.h"
#include "freertos/task.h"
#include "freertos/semphr.h"

static const char *TAG = "pn532";

/* ── IRQ Notification ─────────────────────────────────────────────────── */

static TaskHandle_t s_irq_task_handle = NULL;

static void IRAM_ATTR pn532_irq_isr(void *arg)
{
    (void)arg;
    BaseType_t xHigherPriorityTaskWoken = pdFALSE;
    if (s_irq_task_handle) {
        vTaskNotifyGiveFromISR(s_irq_task_handle, &xHigherPriorityTaskWoken);
    }
    portYIELD_FROM_ISR(xHigherPriorityTaskWoken);
}

/* ── I2C Helpers ──────────────────────────────────────────────────────── */

static esp_err_t i2c_write(pn532_handle_t *h, const uint8_t *data, size_t len)
{
    return i2c_master_write_to_device(h->config.i2c_port, PN532_I2C_ADDR,
                                       data, len, pdMS_TO_TICKS(100));
}

static esp_err_t i2c_read(pn532_handle_t *h, uint8_t *data, size_t len)
{
    return i2c_master_read_from_device(h->config.i2c_port, PN532_I2C_ADDR,
                                        data, len, pdMS_TO_TICKS(100));
}

/* ── Ready Detection ──────────────────────────────────────────────────── */

bool pn532_wait_ready(pn532_handle_t *h, uint32_t timeout_ms)
{
    if (h->config.irq_pin >= 0) {
        /* IRQ-based: wait for falling edge notification */
        s_irq_task_handle = xTaskGetCurrentTaskHandle();
        ulTaskNotifyTake(pdTRUE, 0); /* Clear any pending */

        if (gpio_get_level(h->config.irq_pin) == 0) {
            return true; /* Already ready */
        }

        uint32_t got = ulTaskNotifyTake(pdTRUE, pdMS_TO_TICKS(timeout_ms));
        return (got > 0);
    }

    /* Polling fallback: read I2C status byte */
    TickType_t start = xTaskGetTickCount();
    while ((xTaskGetTickCount() - start) < pdMS_TO_TICKS(timeout_ms)) {
        uint8_t status = 0;
        if (i2c_read(h, &status, 1) == ESP_OK) {
            if (status & PN532_I2C_READY_BIT) return true;
        }
        vTaskDelay(pdMS_TO_TICKS(5));
    }
    return false;
}

/* ── Frame Encoding ───────────────────────────────────────────────────── */

esp_err_t pn532_write_command(pn532_handle_t *h, const uint8_t *cmd, uint8_t cmd_len)
{
    /*
     * I2C frame layout:
     * [PREAMBLE][START1][START2][LEN][LCS][TFI=0xD4][cmd...][DCS][POSTAMBLE]
     */
    uint8_t frame[cmd_len + 8];
    uint8_t len_field = cmd_len + 1; /* +1 for TFI */
    uint8_t lcs = (~len_field) + 1;  /* LEN + LCS = 0x00 mod 256 */

    frame[0] = PN532_PREAMBLE;
    frame[1] = PN532_STARTCODE1;
    frame[2] = PN532_STARTCODE2;
    frame[3] = len_field;
    frame[4] = lcs;
    frame[5] = PN532_HOSTTOPN532;

    uint8_t dcs_sum = PN532_HOSTTOPN532;
    for (int i = 0; i < cmd_len; i++) {
        frame[6 + i] = cmd[i];
        dcs_sum += cmd[i];
    }
    frame[6 + cmd_len] = (~dcs_sum) + 1; /* DCS */
    frame[7 + cmd_len] = PN532_POSTAMBLE;

    esp_err_t err = i2c_write(h, frame, cmd_len + 8);
    if (err != ESP_OK) {
        ESP_LOGE(TAG, "I2C write failed: %s", esp_err_to_name(err));
        return err;
    }

    /* Wait for ACK frame */
    vTaskDelay(pdMS_TO_TICKS(1));
    if (!pn532_wait_ready(h, 100)) {
        ESP_LOGE(TAG, "ACK timeout");
        return ESP_ERR_TIMEOUT;
    }

    uint8_t ack[7]; /* 1 status byte + 6 ACK bytes */
    err = i2c_read(h, ack, 7);
    if (err != ESP_OK) return err;

    /* Validate ACK: status[0] + [0x00 0x00 0xFF 0x00 0xFF 0x00] */
    if (ack[1] != 0x00 || ack[2] != 0x00 || ack[3] != 0xFF ||
        ack[4] != 0x00 || ack[5] != 0xFF) {
        ESP_LOGE(TAG, "Invalid ACK frame");
        return ESP_ERR_INVALID_RESPONSE;
    }

    return ESP_OK;
}

/* ── Frame Decoding ───────────────────────────────────────────────────── */

esp_err_t pn532_read_response(pn532_handle_t *h, uint8_t *buf, uint8_t *len,
                               uint32_t timeout_ms)
{
    if (!pn532_wait_ready(h, timeout_ms)) {
        return ESP_ERR_TIMEOUT;
    }

    /*
     * I2C read: [RDY][PREAMBLE][START1][START2][LEN][LCS][TFI=0xD5][Data...][DCS][POSTAMBLE]
     * Read header first to get length, then full frame.
     */
    uint8_t header[7];
    esp_err_t err = i2c_read(h, header, 7);
    if (err != ESP_OK) return err;

    /* header[0] = ready status byte */
    if (!(header[0] & PN532_I2C_READY_BIT)) {
        return ESP_ERR_NOT_FINISHED;
    }

    /* Validate start code */
    if (header[1] != PN532_PREAMBLE || header[2] != PN532_STARTCODE1 ||
        header[3] != PN532_STARTCODE2) {
        ESP_LOGE(TAG, "Invalid start code: %02X %02X %02X", header[1], header[2], header[3]);
        return ESP_ERR_INVALID_RESPONSE;
    }

    uint8_t data_len = header[4]; /* LEN = TFI + response code + params */
    uint8_t lcs = header[5];

    /* Validate LEN checksum */
    if ((uint8_t)(data_len + lcs) != 0) {
        ESP_LOGE(TAG, "LEN checksum failed");
        return ESP_ERR_INVALID_CRC;
    }

    if (data_len < 2 || data_len > PN532_MAX_DATA_LEN) {
        ESP_LOGE(TAG, "Invalid data length: %d", data_len);
        return ESP_ERR_INVALID_SIZE;
    }

    /* TFI is already in header[6] */
    if (header[6] != PN532_PN532TOHOST) {
        ESP_LOGE(TAG, "Invalid TFI: 0x%02X", header[6]);
        return ESP_ERR_INVALID_RESPONSE;
    }

    /* Read remaining data: (data_len - 1) bytes + DCS + postamble */
    uint8_t remaining = data_len - 1 + 2;
    uint8_t rest[remaining];
    err = i2c_read(h, rest, remaining);
    if (err != ESP_OK) return err;

    /* Verify DCS: TFI + all data bytes + DCS = 0x00 */
    uint8_t dcs_sum = PN532_PN532TOHOST;
    for (int i = 0; i < data_len - 1; i++) {
        dcs_sum += rest[i];
    }
    dcs_sum += rest[data_len - 1]; /* DCS byte */
    if (dcs_sum != 0) {
        ESP_LOGE(TAG, "DCS checksum failed");
        return ESP_ERR_INVALID_CRC;
    }

    /* Copy response data (skip response code byte at rest[0]) */
    uint8_t out_len = data_len - 2; /* minus TFI and response code */
    if (out_len > *len) out_len = *len;

    /* rest[0] = response command code (e.g. 0x03 for GetFirmwareVersion+1) */
    /* We include the response code in the output for caller to check */
    out_len = data_len - 1; /* everything after TFI */
    if (out_len > *len) out_len = *len;
    memcpy(buf, rest, out_len);
    *len = out_len;

    return ESP_OK;
}

/* ── Initialization ───────────────────────────────────────────────────── */
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

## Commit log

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2026-10-07 feat(android): encrypt the Room database with SQLCipher
    The passphrase is a random 32-byte secret stored only in wrapped form,
    encrypted by an AES-GCM key held in the Android Keystore. The database is
    now toms_enc.db; the old plaintext toms.db is deleted on first start.
    Checked on a Tecno Pova 4: the file header is random bytes, not
    'SQLite format 3'. The key cannot leave the device, so unsynced data is
    not recoverable after a phone swap or reset.
2026-10-07 feat(backend): PostgreSQL, migrations and the v2 events schema (Phase 1.4, step 1)
    Replaces the SQLite prototype. Migrations in migrations/ run in order, each
    in a transaction, under an advisory lock so two containers can start safely.
    events table: client event_id (uuid, unique) as the idempotency key,
    device_id, local_seq, terminal_id, delivery_channel, trip and card fields
    (card_uuid, nfc_uid, card_state, declared and actual destination, fare
    version, override reason) and the GPS fix (latitude, longitude, accuracy,
    fix time; all-or-none enforced by a constraint). The original payload is
    kept as jsonb. slave_uid and slot_number are gone. A trip_status view gives
    the latest card state per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
2026-10-07 feat(backend): authentication, device credentials and cleanup (Phase 1.4, step 3)
    Sign-in
    - Admins and conductors sign in at /api/admin/login and
    /api/conductors/login. Passwords are argon2id. Tokens are HS256 JWTs
    with issuer and audience, 8 h for admins and 16 h for conductors, and
    the verifier pins the algorithm. A token stops working as soon as its
    account is deleted.
    - Unknown users cost the same hashing time as wrong passwords and get the
    same answer. 5 failed tries per username block it for 15 minutes (in
    memory: resets on restart, and it is per username, not per IP).
    - There is no seeded account. Create the first admin with
    ADMIN_PASSWORD=... npm run create-admin -- <us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
2026-10-07 feat(backend): dashboard endpoints on the v2 schema (Phase 1.4, step 4a)
    Ports fleet status, audit logs, revenue analytics, CSV export and the
    conductor list from the SQLite prototype to PostgreSQL, all admin-only,
    and adds /api/delivery/summary. They now read trips and card states, not
    slave_uid / slot_number.
    - Occupancy is the number of cards currently out (assigned, not returned),
    not a seat map. A trip open for over 24 h counts as abandoned.
    - Revenue counts trips whose fare was collected, grouped by day in
    REPORT_TIMEZONE (default Asia/Manila), not UTC. Events from a phone with
    a wrong clock are filed under the server's receive time (migration 004).
    - Fleet status carries the ne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
2026-10-07 fix(backend): attach socket.io after Express so admin sockets connect (Phase 1.4, step 4b)
    The live dashboard socket was never reachable: Express was registered on
    the server after socket.io, so both answered the same polling request and
    an authenticated admin could not connect. createServer() now gives Express
    to http.createServer first and attaches socket.io afterwards, and index.ts
    uses it. Found by running the real server end to end; the earlier unit
    tests built the app without the socket.
    6 socket tests (admin accepted; no token, garbage token, non-string
    token, device credential and a deleted admin refused; REST still served;
    a phone upload reaches a connected admin as fleet_update).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
2026-10-07 feat(web): sign-in and the v2 schema (Phase 1.4, step 4b)
    The dashboard had no login and called the API with a hard-coded
    http://localhost:3000. It now:
    - shows a sign-in page and sends the token on every request through one
    client (src/lib/api.ts); the API address comes from VITE_API_URL, empty
    meaning same origin. The token is kept in sessionStorage, so closing the
    tab signs out. An expired session returns to sign-in; a wrong password
    does not count as one.
    - connects the live socket with the token
    - downloads the CSV through the authenticated client (a plain link cannot
    send a header) and says when the export was cut at 50,000 rows
    - shows the v2 fields in the audit log: card UI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
2026-10-08 chore: move the v1 Flutter app and ESP32 firmware into archive/
    esp32_master, esp32_slave, toms_mobile and shared_lib now live under
    archive/. shared_lib moved with the firmware because both projects reach
    it by relative path (../shared_lib, ../../shared_lib); those paths still
    resolve from the new location.
    All 3,466 files are exact renames (git mv), so history follows with
    git log --follow. Nothing was deleted. archive/README.md says what each
    folder is and why it is kept. The top-level README points to it, and
    build-output patterns in .gitignore and path mentions in the v2 docs and
    one test comment were updated.
    The ESP-NOW variants and stm32_slave_monitor were never committed and
    are n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
    [partitions.csv]
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2026-10-08 feat(android): speed- and one-hand-optimized UI redesign for conductors
    Replaces test-harness screens with an operational UI built for speed, one-hand thumb reach, and high-contrast sunlight visibility:
    - Theme & Colors: High-contrast light palette (minimum 4.5:1 WCAG ratio, up to 18.5:1), large text (72sp fare display), 64dp minimum touch targets.
    - Feedback: Haptic vibration waveform + audio ToneGenerator cues (Done, Refused, Opened). Color is never the sole indicator.
    - Handedness: Left/Right preference in settings; mirrors Undo/Clear and TabBar placement.
    - Board Screen: Quick 'To' destination picker, huge live-updating fare total, passenger buttons (Regular, Student, PWD, Senior) with i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
2026-10-08 feat(android): Retrofit event uploader and device sync configuration
    - Network Client: Retrofit 2.11 + OkHttp 4.12 with kotlinx.serialization converter, 15s timeouts, and cleartext HTTP enabled for local dev/testing.
    - RetrofitEventUploader: Serializes pending outbox batch into backend EventUploadEnvelope schema ('events', 'delivery_channel'); transmits with Bearer token authentication to POST /api/events. Both 'accepted' and 'duplicates' are acknowledged and marked delivered in the local Room outbox.
    - DeviceConfigStore & PrefsDeviceConfig: Manages device_id, serverUrl (default http://127.0.0.1:3000 for adb reverse or local testing), and enrolled deviceToken.
    - MoreScreen (Diagnostics): Con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
2026-10-08 feat(web): readable Live Feed lines for trips and card changes
    feedMessage() turns each event into a line: how many boarded and where
    to, what a group paid, who got off when the card came back, and an
    unmistakable line for an unpaid return or a lost card. An unknown event
    type or a phone with no vehicle still produces a line.
    Found by watching a real upload reach the open dashboard: the feed stayed
    empty because the Vite dev server kept serving a stale copy of the page
    that called feedMessage without importing it. Restarting the dev server
    fixed it; the source and the production build were always correct.
    4 tests. Web: 41 tests.
2026-10-08 fix(android): status chips wrap instead of being cut off; Device ID row no longer cramped
    Seen in screenshots of the real phone: on a 720 px wide screen the third
    status chip ('10 unsent') was cut off at the right edge and showed as
    '10 uns...', and on the More screen the long Device ID ran straight into
    its label ('Device IDf191f68f...').
    The chips now sit in a wrapping row and never break their own text. The
    fact rows give the value the remaining width and align it right.
    Not checked on the phone: it was unplugged when the fix was built. The
    change is layout only and the 154 / 149 Android unit tests still pass, but
    those tests do not look at layout.
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2026-10-12 fix(backend): create and chown /app/uploads/fares before switching to non-root user in Dockerfile
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2026-10-12 fix(web): proxy /api, /uploads, and /socket.io through Vite dev server for mobile and LAN access
2026-10-12 feat(web): enhance Web NFC card enrollment and NDEF receipt URL tag writing
    - Web NFC Integration: Full implementation of Google Chrome's Web NFC sample (window.NDEFReader) with AbortController lifecycle handling, serial number uppercase normalization, and navigator.vibrate haptic feedback.
    - NDEF URL Tag Writing: Option to automatically write the static receipt URL (/r/:card_uuid) into the physical card's NDEF memory upon enrollment or from the printable sticker modal via ndef.write().
    - HTTPS Support: Added @vitejs/plugin-basic-ssl in vite.config.ts for secure context compliance on mobile devices.
    - Tests & Build: All 44 web tests passing and clean Vite production build.
2026-10-12 feat(docker): serve the web dashboard from the compose stack over HTTPS
    - toms_web/Dockerfile builds the app and serves it with nginx on 443 (published as 5173), proxying /api, /uploads and /socket.io to the api container.
    - Self-signed certificate is generated on first start into a volume so it survives restarts; TLS_EXTRA_IPS adds the PC's LAN address.
    - Web now has the same restart: unless-stopped policy as the api and db, so it no longer depends on a terminal running Vite.
    - Regenerated package-lock.json so npm ci passes (missing @emnapi entries).
2026-10-12 feat(android): single Clear button, and start each group fresh after a tap
    - Board: replace the Undo and Clear pair with one full-width Clear button; Undo is removed from the view model and the handedness note.
    - A successful card tap now resets the passenger group to one regular, so the screen no longer looks like it still holds the group that just boarded. The destination is kept. Tapping an in-use card leaves the group being built alone.
    - Tests: reset-after-tap and in-use-tap cases added (the reset test fails without the change).
2026-10-12 feat(android): shift flow in the view model - start, block, end, write off
    - Every trip and payment is tagged with the open shift; a tap with no open shift is refused.
    - A different conductor, vehicle or route cannot start while a shift is open: the old shift's End Shift prompt is shown first, and its unpaid trips are asked about.
    - End Shift asks once about unpaid trips: go back and collect, or record them as uncollected. Uncollected is a write-off, never a terminal return. A double tap ends the shift once.
    - A card that really came back unpaid is written off and resolved, keeping its true terminal return and with no invented release.
    - Tests: 11 new flow tests; existing view-model tests no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
2026-10-12 fix(android): the Board card follows Paid and Return on a just-started trip
    After a card tap starts a trip, the Board showed the card as unpaid for good: the card was drawn with a fixed unpaid state, and Paid and Return only refreshed the 'already on a trip' result, not the 'started' one. Collect showed the right state, so the two screens disagreed. A started result now carries the card's state, and Paid and Return update it. Another trip being paid leaves the card on screen alone.
    Tests: three new (pay, return, and a different trip), each of the first two and the wrong-trip guard fail without the fix. The line that draws the state on screen is not covered by a unit test; it was checked by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
2026-10-13 docs: map the research questions to what is built and what the paper may claim
    Per question: what answers it, what the build supports, what the paper must not say yet, and what is missing. Notes that the paper words the questions two ways, that passenger counting is manual in this build, and that RQ4 has no manual baseline, ground truth, criteria mapping, sync formula or stated H0 test yet.
2026-10-28 feat(backend): pre-printed cards that are paired to an NFC chip later
    Cards can now exist before a chip is attached. Migration 008 makes nfc_uid
    nullable, adds the unpaired status and a unique serial, and requires a UID for
    active or suspended cards.
    New admin endpoints: batch create (1-500, any serial clash creates nothing),
    pairing lookup, pair (once only) and unpair, plus GET /api/config for
    PUBLIC_BASE_URL. The approved-cards list skips cards with no chip and the card
    list sorts serials by number.
    PATCH/DELETE with a malformed card id now answer 400, and activating an
    unpaired card answers 409 instead of a 500.
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2026-10-28 fix(web): save 0% discounts, show load errors, fix passenger message
    A typed 0% student, PWD or senior discount was saved as 20%. The fare
    effective-date default used the UTC day. A card with no trip showed Receipt
    not found because the request did not ask for JSON. Route snapping called
    OSRM over http, which browsers block on an https site.
    Card Registry, Conductors, Fleet Manager, Analytics and Audit Logs now show a
    message with a Try again button when loading fails instead of an empty page.
2026-10-28 fix(web): usable layout on phone-sized screens
    The fixed 280px sidebar crushed the page on phones. Below 900px it becomes a
    menu button with a backdrop, content uses the full width, tables scroll inside
    their panel and multi-column grids stack.
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2026-10-30 feat(web): print cards on A4, Letter or custom paper as a PDF
    The card designer gets a Print on paper sheets section. It lays the cards out
    to fill each sheet with a cutting gap, an optional border and cutting marks,
    and picks portrait or landscape and upright or sideways for the most cards per
    sheet. With a back design the pages alternate front and back, with each back
    mirrored to land behind its own front for the printer's flip edge.
    A preview shows sheet 1, and the PDF stores each design once and draws every QR
    code as vector shapes, so a batch stays small.
    Every QR now has a white quiet zone of 4 modules (in the PDF, the ZIP export
    and the preview). Without it the codes did not scan wh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
2026-10-30 feat(backend): replace the chip on a card, keeping its printed QR
    POST /api/cards/:uuid/replace swaps the chip in one step, so a card is never
    left without one. The serial, label, QR id and history stay. A lost card that
    gets a new chip is back in service; a suspended one stays suspended. The old
    and new chip are recorded together in the history.
    Refuses a chip that already belongs to another card, the chip already on the
    card, a card with no chip (pair it instead) and a retired card. Warns about an
    open trip first, like the other changes that could strand a passenger.
2026-10-30 feat(web): Replace chip action reuses the tap-and-confirm panel
    A Replace chip item in the card menu opens the pairing panel in replace mode:
    tap the new chip, add an optional reason, confirm. The panel says the printed QR
    and serial stay and the old chip stops working, and asks again when the card has
    an open trip. There is no Undo, since this is not a first pairing.
2026-10-30 feat(backend): change many cards at once, look cards up, export the list
    POST /api/cards/bulk changes the status or vehicle of a list of cards, or of
    everything matching the registry filters (up to 500). It is all or nothing: if
    any card cannot make the move, nothing changes and the answer lists every
    card that was the problem. Each card is checked against the same lifecycle
    rules, reason requirement and open-trip warning as a single change, and gets
    its own history row.
    POST /api/cards/lookup returns the full cards for a list or filter, so the
    designer can reprint cards that already exist. GET /api/cards/export downloads
    the list as a CSV with the registry's filters, including when each ca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
2026-10-30 feat(web): select many cards, change them together, reprint and export
    Each registry row has a checkbox, and each vehicle group a select-all box. A bar
    appears with the count and what is selected, and offers only the status changes
    every selected card can make, plus moving them to a vehicle or the spare pool.
    Select all that match switches from the ticked cards to everything the current
    filters match, up to 500. The change asks for a reason when needed and warns
    about open trips for the whole group. If the server refuses, the dialog lists
    which cards were the problem and nothing is changed.
    Reprint sends the selected cards to the designer, which loads them as they are
    so their QR codes stay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
2026-10-31 fix(deploy,api,web): review fixes before the OVH deploy
    Deploy:
    - Serve the app at toms.perchbuilds.me (one A record). The apex and www stay on
    GitHub Pages, so the old www redirect and apex records are removed.
    - Caddy sends every request to the web container, so a printed QR on /r/<uuid>
    reaches the app: an admin sees the pairing screen, a passenger sees the receipt.
    - Caddy overwrites X-Forwarded-For with the address it sees, and sends a
    report-only Content-Security-Policy and framing and referrer headers.
    - backup.sh selects the compose file itself, streams uploads from the API
    container, and renames files into place only when complete, so a failed run
    leaves no partial backup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
2026-10-31 fix(backend): keep the device config version within what ingest accepts as fare_version
    The version was a 31-bit integer, but ingest refuses a trip whose fare_version is above 1,000,000, so a phone using it would have had every trip rejected. It is now 1 to 1,000,000, and a test sends a trip carrying it through ingest.
2026-10-31 feat(android): download fares, stops and discounts from the server
    The phone no longer charges from TestConfig. It fetches GET /api/device/config with its device token, checks every number (version 1..1,000,000, two or more stops with valid positions, fare and discount ranges), saves the last good copy in Room (schema 5, new server_config table, tested migration) and works from that offline. A failed fetch, a 404 or a response that fails its checks changes nothing and says why on More.
    With no saved fares a release build starts empty: the Board says 'No fares loaded. Connect and sync.' and a tap starts no trip (a card already out still shows its trip). TestConfig stays for unit tests and fo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
2026-11-01 fix(android): a release build starts with no server address and asks for one
    DEFAULT_URL was http://127.0.0.1:3000, which a release build blocks. The default is now a build setting: debug keeps the local URL, release is empty. With no address the Board and More say 'Set the server address on More', and nothing uploads, fetches fares or syncs cards (no attempt is counted against waiting events either). Setting an address fetches straight away. The hostname is not built in. Also fixes a flaky FaresLoadingTest that waited for the fares but not the card list.
2026-11-01 ci(android): build the release variant so R8 runs on every push
    assembleDebug never runs R8, so a missing keep rule only showed up on a phone. :app:assembleRelease (unsigned) now runs after assembleDebug. It builds today with no R8 warnings, so proguard-rules.pro is unchanged: Room, kotlinx.serialization, Retrofit and OkHttp ship consumer rules, and SQLCipher is kept in app/proguard-rules.pro.
2026-11-01 feat(deploy): read-only check of the live server (deploy/verify.sh)
    bash deploy/verify.sh https://toms.perchbuilds.me
    Prints one PASS or FAIL line per check and exits 1 if any fail. It needs only
    curl and makes read-only, unauthenticated requests: no logins, no writes, no
    admin or device credentials.
    Checks: the certificate is valid without -k; HTTP redirects to HTTPS; / is
    200 HTML; /api/health is 200 with status ok; /api/config and
    /api/device/config are 401 without a login; a malformed receipt link is a 4xx,
    not a 5xx; a malformed card link is a 4xx or the app page; HSTS, nosniff and a
    Content-Security-Policy header are present; X-Powered-By is absent.
    The port scan is not run. The scr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
2026-11-01 fix(scripts): make the pilot prompts work in a real terminal; document the pilot tools
    Found in review of the pilot PR:
    - The password reader never turned on raw mode or resumed input, so in a
    real terminal it would have sent nothing until Enter. It now attaches its
    listener, then enables raw mode and resumes, and restores the terminal on
    every exit.
    - Both readers only handled string input. They now accept a string or a
    Buffer, since iterating a Buffer yields numbers that never match a character.
    - The admin username was hidden like the password. It is now shown as it is
    typed. The admin password and a new conductor's password stay hidden.
    The script suite runs 29 tests, all pass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
2026-11-01 feat(android): wire conductor authentication to POST /api/conductors/login
    1. Adds ConductorLoginRequest/Response DTOs and POST /api/conductors/login to TomsApiService.
    2. Implements ConductorAuthService in RetrofitEventUploader, querying the server and returning the conductor's display name or detailed error messages on 401/429.
    3. Implements ServerSessionRepository, replacing StubSessionRepository as the default binding in DataModule. In test mode (-PtestFares=true), allows fallback if offline.
    4. Adds 7 unit tests covering valid credentials, 401 rejection, 429 rate limiting, and offline/blank input validations.
    5. Verified live on Tecno Pova 4: unauthenticated/fake usernames are now activ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
2026-11-02 fix(security): resolve audit findings across web, backend, and deployment
    Backend:
    - S3: Enforce strict vehicle boundary in GET /api/cards/approved for device
    tokens. Ignores query param ?vehicle_id= for devices, preventing horizontal
    enumeration of other vehicles' card registries.
    - C3: Remove dead and dangerous unscoped POST/GET /api/routes/:id/stops that
    wiped path-based stop geofences.
    - D4: Pin multer to exact version 2.4.0 in package.json.
    Deployment & Infrastructure:
    - S4: Promote Content-Security-Policy-Report-Only to enforcing
    Content-Security-Policy in Caddyfile with verified external origins.
    - S5: Enable server_tokens off in Nginx configuration to suppress version banner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
2026-11-03 feat(android): implement Phase 1.6 UplinkManager with anti-flapping hysteresis & auto-drain
    1. Implements UplinkManager and pure UplinkCoordinator with 3.5-second anti-flapping hysteresis:
    - Tracks cellular (mobile data) vs Wi-Fi vs offline dead zones using Android ConnectivityManager NetworkCallback.
    - Prevents flapping on weak 1-bar cellular signals by requiring 3.5s of uninterrupted validated connectivity before transitioning to UplinkState.Online.
    - Rapid signal drops cancel pending timers immediately and revert to UplinkState.Offline.
    2. Auto-Drain Queue Recovery:
    - Emits uplinkRestored upon exiting dead zones and achieving stable connectivity.
    - SyncViewModel automatica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
2026-11-03 fix(ble): synchronize CCCD descriptor writes and enable immediate service UUID discovery
    1. Fixes scan matching to immediately discover Return Machine via Service UUID 544F4D53-5245-5455-524E-414348494E45 without waiting for device name in scan response.
    2. Synchronizes CCCD descriptor writes via onDescriptorWrite with CompletableDeferred and Mutex, ensuring paid_check (0x03) notification subscription is reliably established on the ESP32.
    3. Automatically triggers bonding on initial connection and clears stale GATT cache via refreshGatt().
    4. Serializes writeCharacteristic with response for state_update and time_sync.
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
